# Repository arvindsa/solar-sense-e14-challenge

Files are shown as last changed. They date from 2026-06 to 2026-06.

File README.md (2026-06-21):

# SolarSense: Smart Solar Panel Monitoring System

A comprehensive IoT system for real-time solar panel soiling detection using multi-sensor fusion and edge AI. This project monitors three solar panels -one kept clean as a reference baseline to quantify soiling-induced efficiency losses in real time.

**Important: There is an issue with charging circuit. So do not replicate this project unless you know electronics well.**

## Project Overview

SolarSense uses a clean reference panel to cancel out weather effects completely (both panels see the same sky), leaving only soiling-induced losses measurable. The system combines:

- **Hardware**: Custom STM32L476 sensor board with CAN telemetry
- **Gateway**: Arduino UNO Q with dual STM32U585 (bare-metal HAL) and Linux bridge
- **Dashboard**: LabVIEW-based live visualization
- **AI**: Edge Impulse model for clean/alert/soiled classification

**Current Status**: Phase 1 (data collection and live dashboard) complete. Full pipeline implemented but pending end-to-end hardware validation.

Write-up: https://community.element14.com/challenges-projects/design-challenges/on-the-line/b/projects/posts/solarsense---edge-ai-for-optimal-cleaning-of-solar-panels

## Repository Structure

```
firmware/
├── solar-sense-stm32l476/       # Main sensor board (STM32L476RGT6)
├── arduinoq-stm32u585/          # Gateway STM controller (bare-metal HAL)
│   └── bridge/                  # CAN frame bridging logic
└── arduinoq-linux/              # Gateway Linux side (Python bridge)

labview/                         # Dashboard VIs for Window
hardware/                        # PCB schematics and production files
```

Do not use the Python file inside the labview folder. It's only for testing purpose

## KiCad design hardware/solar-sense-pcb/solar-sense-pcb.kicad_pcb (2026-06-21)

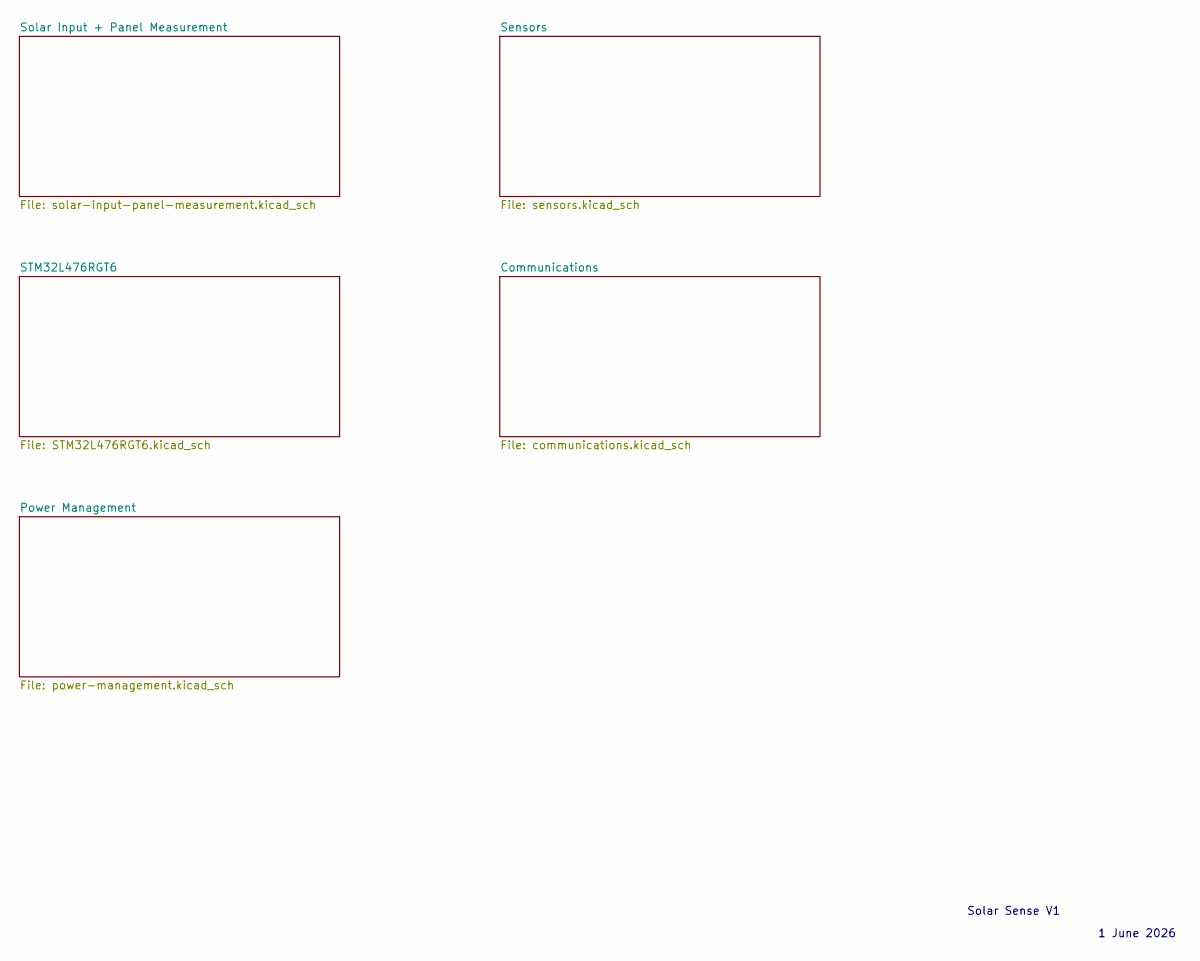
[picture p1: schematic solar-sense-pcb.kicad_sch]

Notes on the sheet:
1 June 2026
Solar Sense V1

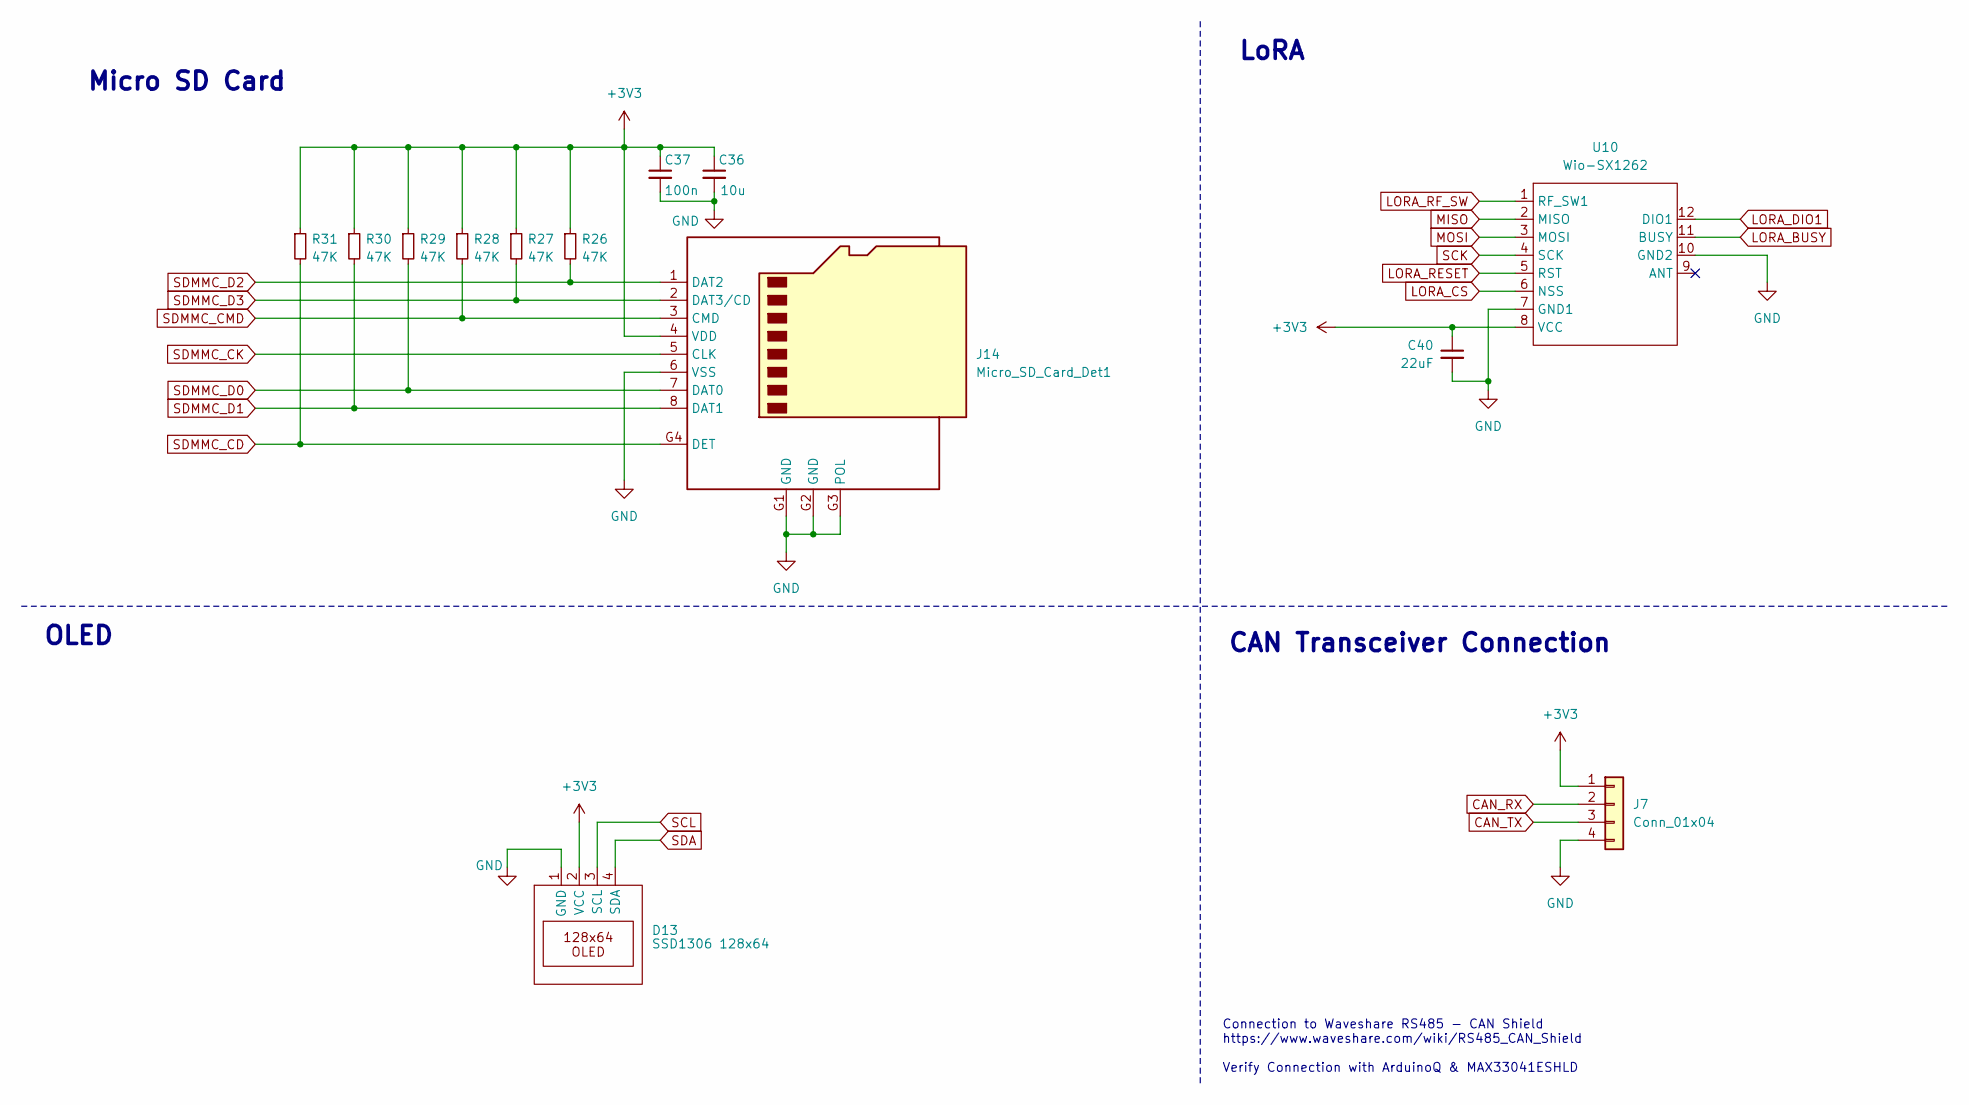
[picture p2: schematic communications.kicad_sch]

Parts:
C36: 10u; C_0603_1608Metric_Pad1.08x0.95mm_HandSolder
C37: 100n; C_0603_1608Metric_Pad1.08x0.95mm_HandSolder
C40: 22uF; C_0603_1608Metric
D13: SSD1306 128x64; JST_XH_B4B-XH-A_1x04_P2.50mm_Vertical
J7: Conn_01x04; JST_XH_B4B-XH-A_1x04_P2.50mm_Vertical
J14: Micro_SD_Card_Det1; microSD Molex 47309-2651
R26, R27, R28, R29, R30, R31: 47K; R_0603_1608Metric
U10: Wio-SX1262; Wio-SX1262 PCB Package

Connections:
+3V3: C36.1, C37.1, C40.1, D13.2 (VCC), J7.1, J14.4 (VDD), R26.1, R27.1, R28.1, R29.1, R30.1, R31.1, U10.8 (VCC); also elsewhere on the board
CAN_RX: J7.2; also elsewhere on the board
CAN_TX: J7.3; also elsewhere on the board
GND: C36.2, C37.2, C40.2, D13.1 (GND), J7.4, J14.6 (VSS), J14.G1 (GND), J14.G2 (GND), J14.G3 (POL), U10.7 (GND1), U10.10 (GND2); also elsewhere on the board
LORA_BUSY: U10.11 (BUSY); also elsewhere on the board
LORA_CS: U10.6 (NSS); also elsewhere on the board
LORA_DIO1: U10.12 (DIO1); also elsewhere on the board
LORA_RESET: U10.5 (RST); also elsewhere on the board
LORA_RF_SW: U10.1 (RF_SW1); also elsewhere on the board
MISO: U10.2 (MISO); also elsewhere on the board
MOSI: U10.3 (MOSI); also elsewhere on the board
SCK: U10.4 (SCK); also elsewhere on the board
SCL: D13.3 (SCL); also elsewhere on the board
SDA: D13.4 (SDA); also elsewhere on the board
SDMMC_CD: J14.G4 (DET), R31.2; also elsewhere on the board
SDMMC_CK: J14.5 (CLK); also elsewhere on the board
SDMMC_CMD: J14.3 (CMD), R28.2; also elsewhere on the board
SDMMC_D0: J14.7 (DAT0), R29.2; also elsewhere on the board
SDMMC_D1: J14.8 (DAT1), R30.2; also elsewhere on the board
SDMMC_D2: J14.1 (DAT2), R26.2; also elsewhere on the board
SDMMC_D3: J14.2 (DAT3/CD), R27.2; also elsewhere on the board

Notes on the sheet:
Micro SD Card
CAN Transceiver Connection
Connection to Waveshare RS485 - CAN Shield https://www.waveshare.com/wiki/RS485_CAN_Shield Verify Connection with ArduinoQ & MAX33041ESHLD
LoRA
OLED

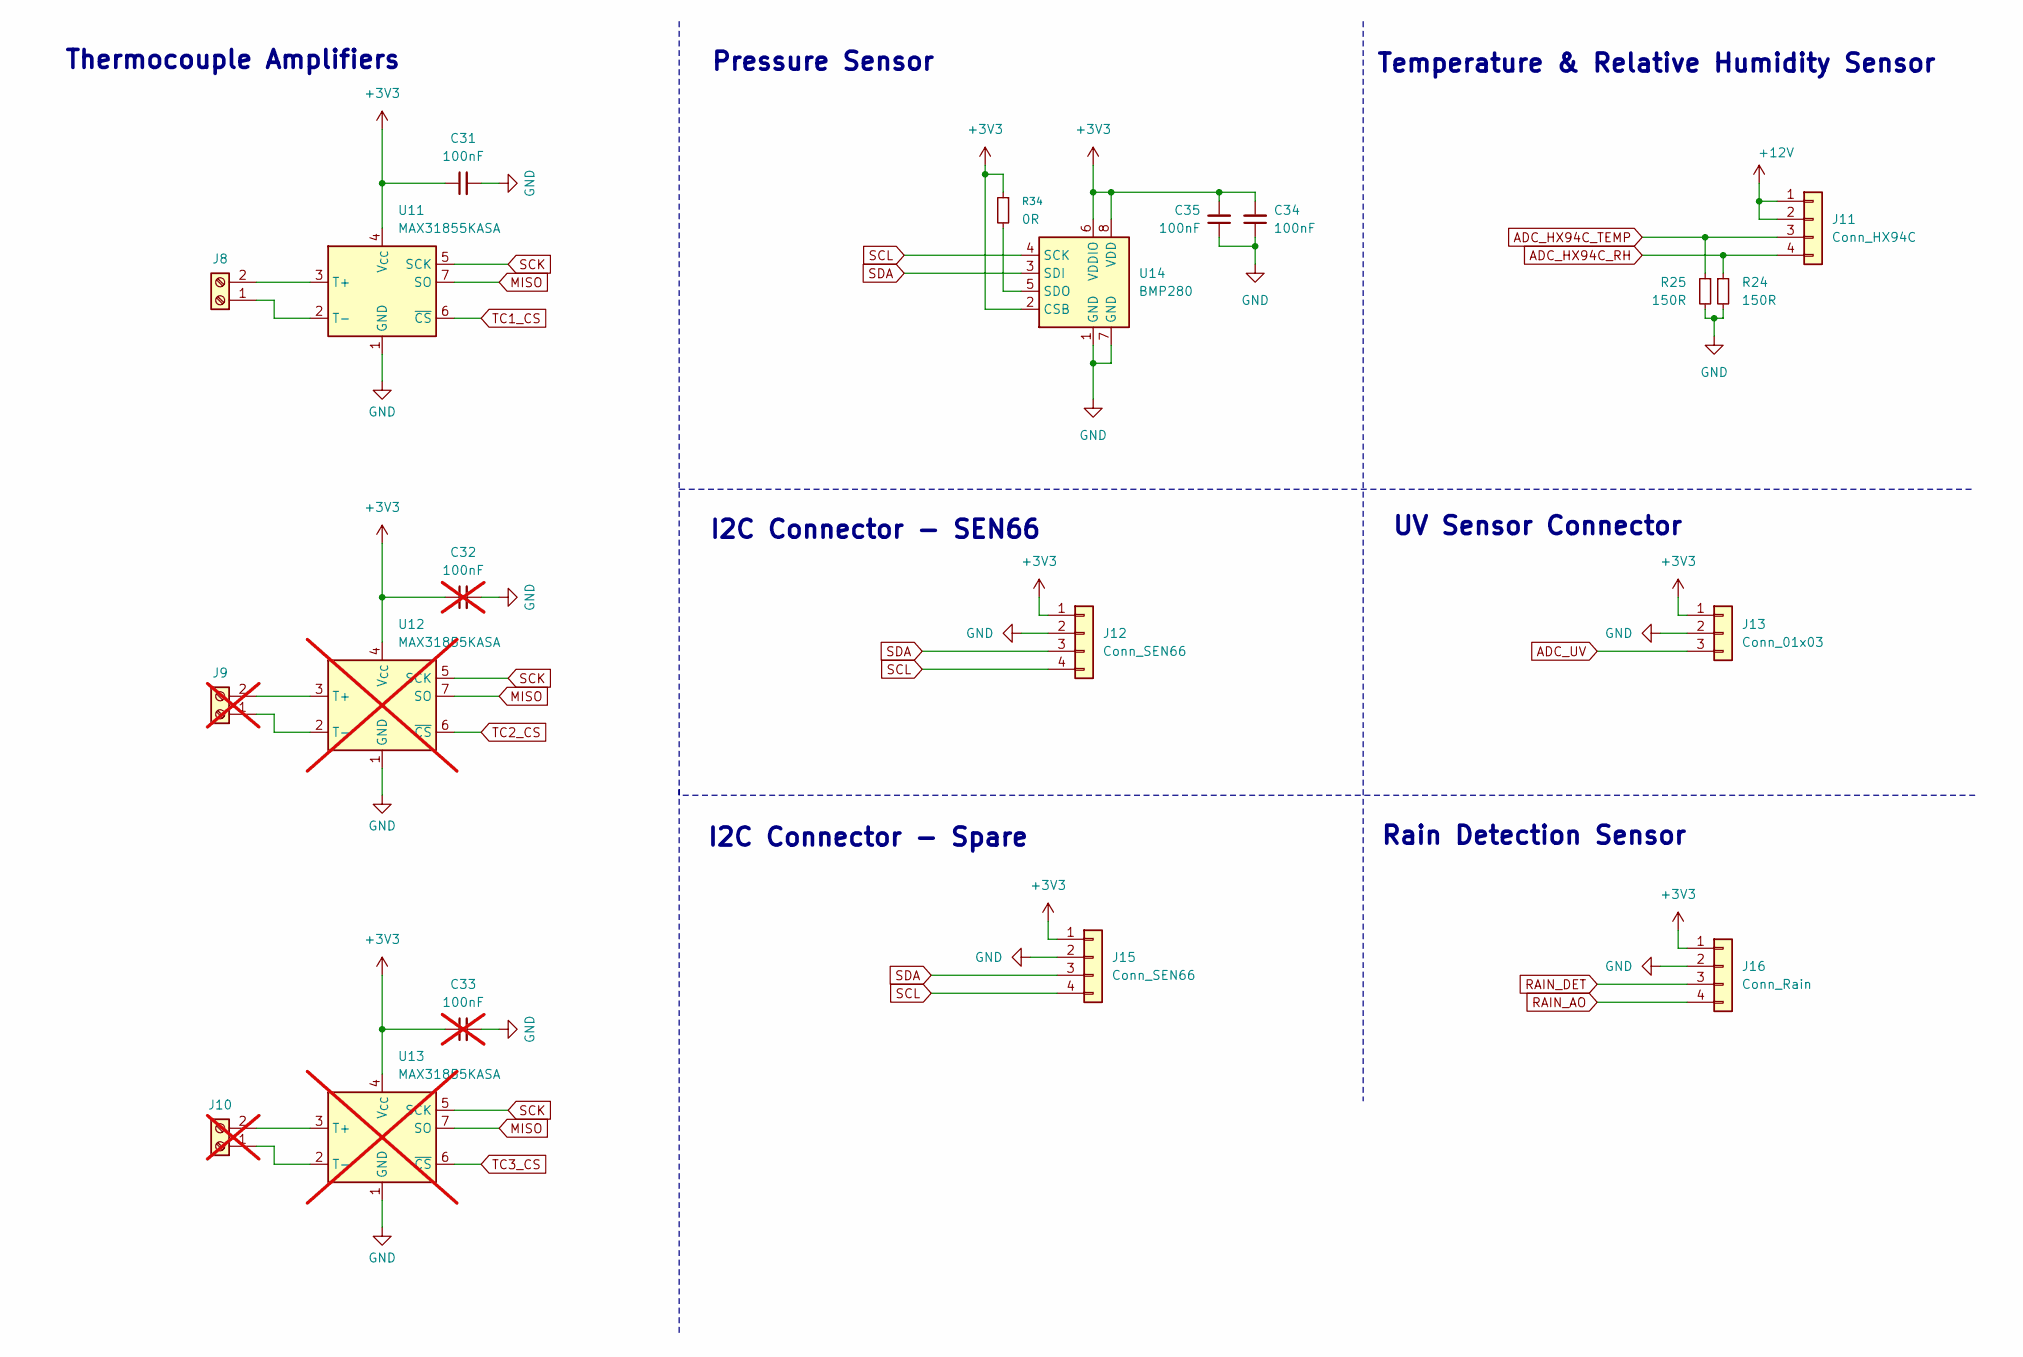
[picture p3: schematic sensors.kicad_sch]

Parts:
C31, C34, C35: 100nF; C_0603_1608Metric
C32, C33: 100nF; C_0603_1608Metric; not fitted
J8: Screw_Terminal_01x02; TerminalBlock_4Ucon_1x02_P3.50mm_Vertical
J9, J10: Screw_Terminal_01x02; TerminalBlock_4Ucon_1x02_P3.50mm_Vertical; not fitted
J11: Conn_HX94C; JST_XH_B4B-XH-A_1x04_P2.50mm_Vertical
J12, J15: Conn_SEN66; JST_XH_B4B-XH-A_1x04_P2.50mm_Vertical
J13: Conn_01x03; JST_XH_B3B-XH-A_1x03_P2.50mm_Vertical
J16: Conn_Rain; JST_XH_B4B-XH-A_1x04_P2.50mm_Vertical
R24, R25: 150R; LED_0805_2012Metric
R34: 0R; R_0603_1608Metric
U11: MAX31855KASA; SOIC-8_3.9x4.9mm_P1.27mm
U12, U13: MAX31855KASA; SOIC-8_3.9x4.9mm_P1.27mm; not fitted
U14: BMP280; Bosch_LGA-8_2x2.5mm_P0.65mm_ClockwisePinNumbering

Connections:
+3V3: C31.1, C32.1, C33.1, C34.2, C35.2, J12.1, J13.1, J15.1, J16.1, R34.1, U11.4 (V_{CC}), U12.4 (V_{CC}), U13.4 (V_{CC}), U14.2 (CSB), U14.6 (VDDIO), U14.8 (VDD); also elsewhere on the board
+12V: J11.1, J11.2; also elsewhere on the board
ADC_HX94C_RH: J11.4, R24.1; also elsewhere on the board
ADC_HX94C_TEMP: J11.3, R25.1; also elsewhere on the board
ADC_UV: J13.3; also elsewhere on the board
GND: C31.2, C32.2, C33.2, C34.1, C35.1, J12.2, J13.2, J15.2, J16.2, R24.2, R25.2, U11.1 (GND), U12.1 (GND), U13.1 (GND), U14.1 (GND), U14.7 (GND); also elsewhere on the board
MISO: U11.7 (SO), U12.7 (SO), U13.7 (SO); also elsewhere on the board
unnamed: J8.1, U11.2 (T-)
unnamed: J8.2, U11.3 (T+)
unnamed: J9.1, U12.2 (T-)
unnamed: J9.2, U12.3 (T+)
unnamed: J10.1, U13.2 (T-)
unnamed: J10.2, U13.3 (T+)
unnamed: R34.2, U14.5 (SDO)
RAIN_AO: J16.4; also elsewhere on the board
RAIN_DET: J16.3; also elsewhere on the board
SCK: U11.5 (SCK), U12.5 (SCK), U13.5 (SCK); also elsewhere on the board
SCL: J12.4, J15.4, U14.4 (SCK); also elsewhere on the board
SDA: J12.3, J15.3, U14.3 (SDI); also elsewhere on the board
TC1_CS: U11.6 (~CS); also elsewhere on the board
TC2_CS: U12.6 (~CS); also elsewhere on the board
TC3_CS: U13.6 (~CS); also elsewhere on the board

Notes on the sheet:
I2C Connector - SEN66
I2C Connector - Spare
Pressure Sensor
UV Sensor Connector
Temperature & Relative Humidity Sensor
Thermocouple Amplifiers
Rain Detection Sensor

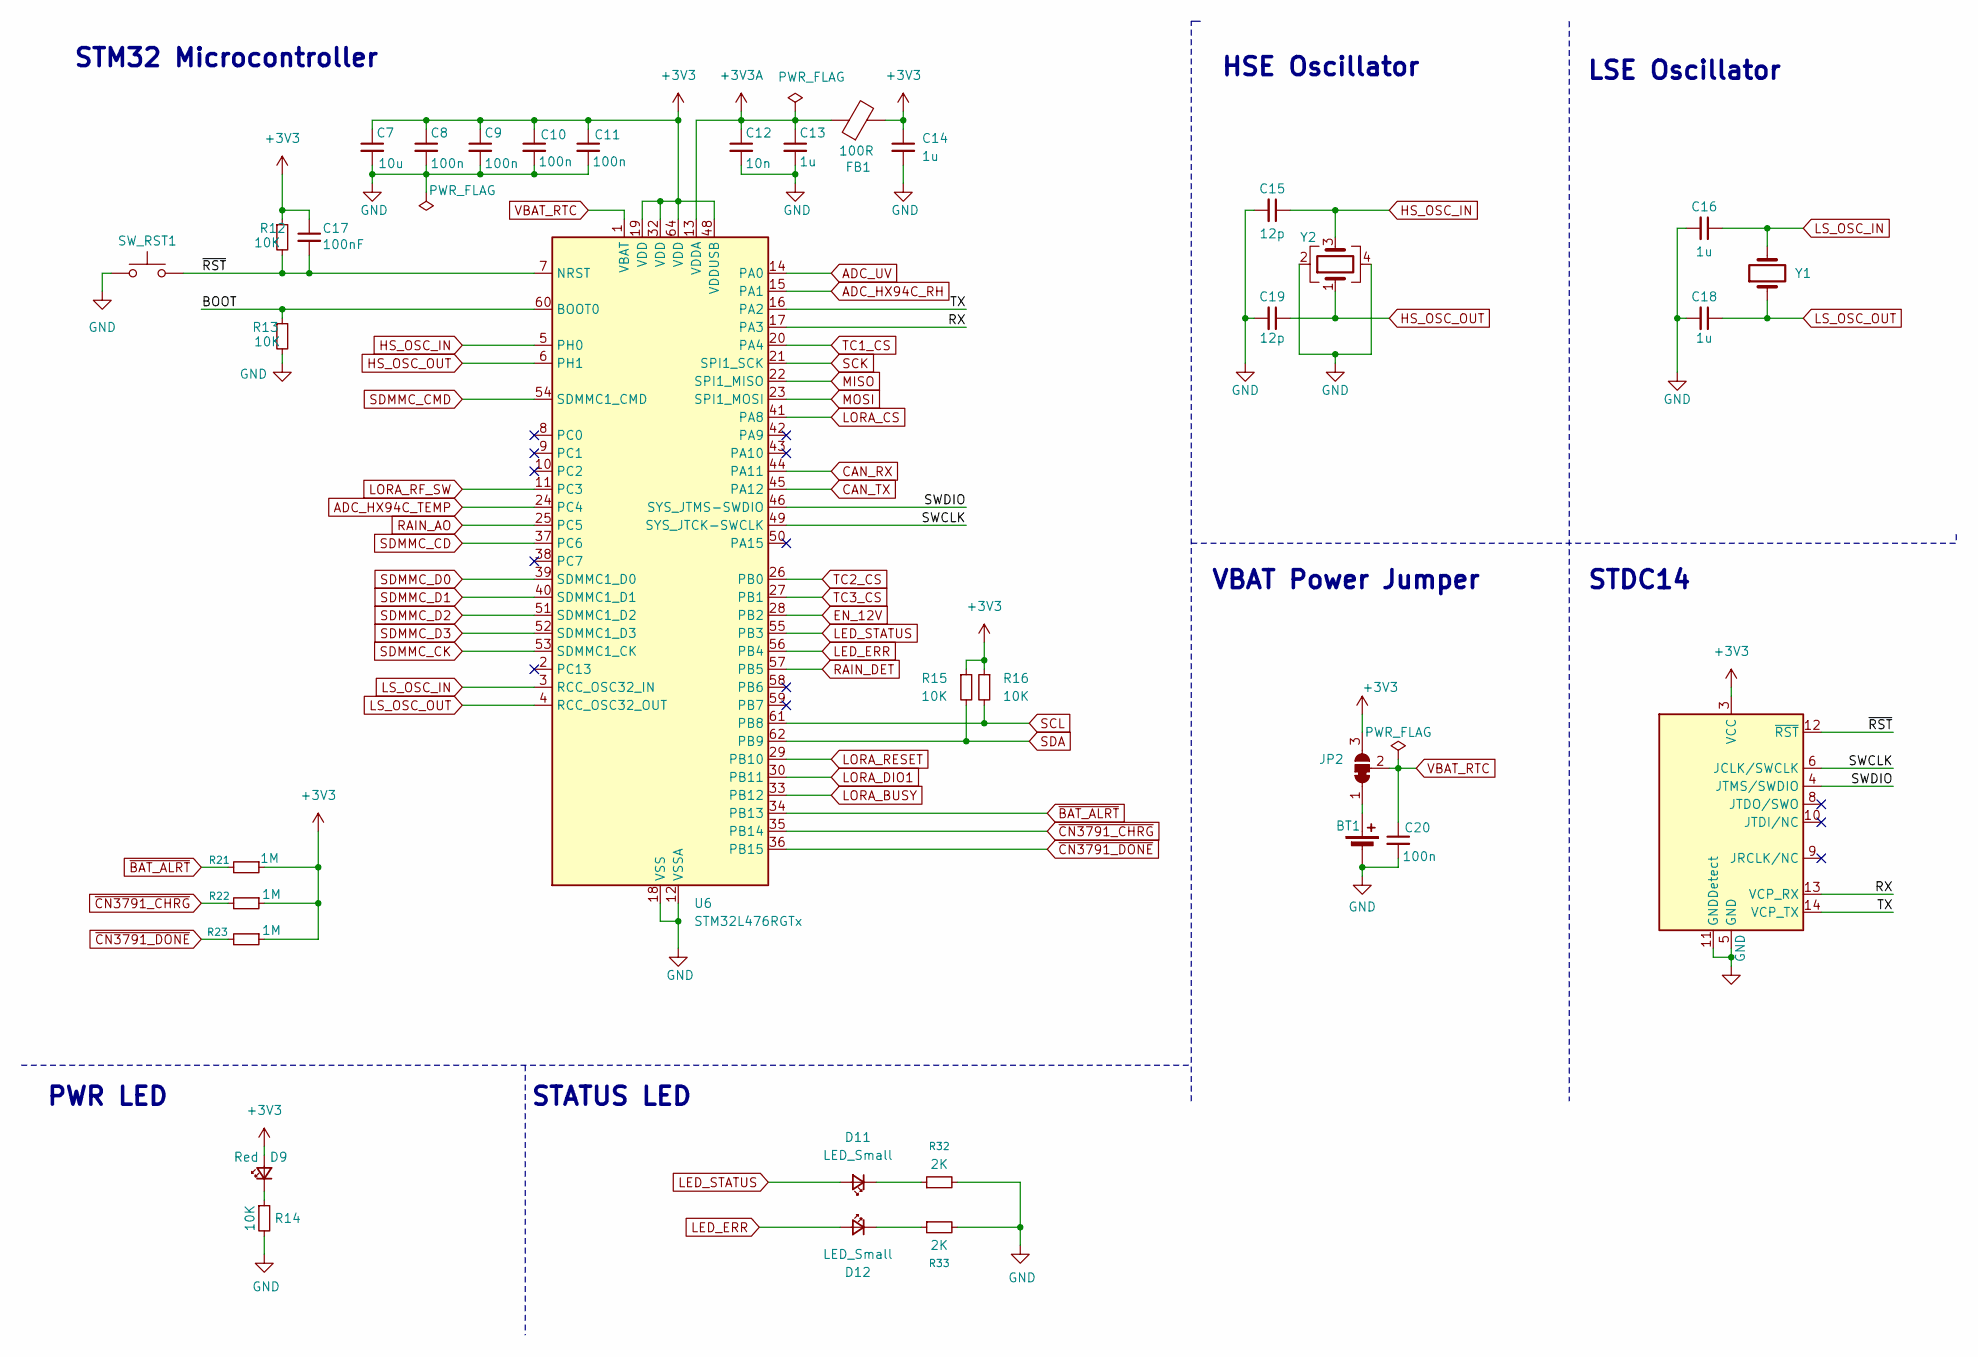
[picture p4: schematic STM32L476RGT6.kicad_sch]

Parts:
BT1: Battery_Cell; CH7410-2032LF
C7: 10u; C_0603_1608Metric_Pad1.08x0.95mm_HandSolder
C8, C9, C10, C11, C20: 100n; C_0603_1608Metric_Pad1.08x0.95mm_HandSolder
C12: 10n; C_0603_1608Metric_Pad1.08x0.95mm_HandSolder
C13, C14, C16, C18: 1u; C_0603_1608Metric_Pad1.08x0.95mm_HandSolder
C15, C19: 12p; C_0603_1608Metric_Pad1.08x0.95mm_HandSolder
C17: 100nF; C_0603_1608Metric
D9: Red; LED_0603_1608Metric_Pad1.05x0.95mm_HandSolder
D11, D12: LED_Small; LED_0603_1608Metric
FB1: 100R; R_0603_1608Metric_Pad0.98x0.95mm_HandSolder
J6: Conn_ST_STDC14; PinHeader_2x07_P1.27mm_Vertical_SMD
JP2: SolderJumper_3_Bridged12; SolderJumper-3_P1.3mm_Bridged12_RoundedPad1.0x1.5mm
R12, R13, R15, R16: 10K; R_0603_1608Metric
R14: 10K; R_0603_1608Metric_Pad0.98x0.95mm_HandSolder
R21, R22, R23: 1M; R_0603_1608Metric
R32, R33: 2K; R_0603_1608Metric
SW_RST1: SW_Push; SW_Tactile_SPST_NO_Straight_CK_PTS636Sx25SMTRLFS
U6: STM32L476RGTx; LQFP-64_10x10mm_P0.5mm
Y1: CM7V-T1A-32.768kHz-9pF-20PPM-TA-QC; Crystal_SMD_3215-2Pin_3.2x1.5mm
Y2: 7M-16.000MAAJ-T; Crystal_SMD_TXC_7M-4Pin_3.2x2.5mm

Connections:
+3V3: C7.1, C8.1, C9.1, C10.1, C11.1, C14.1, C17.1, D9.2 (A), FB1.2, J6.3 (VCC), JP2.3 (B), R12.1, R15.1, R16.1, R21.1, R22.1, R23.1, U6.19 (VDD), U6.32 (VDD), U6.48 (VDDUSB), U6.64 (VDD); also elsewhere on the board
+3V3A: C12.1, C13.1, FB1.1, U6.13 (VDDA)
/STM32L476RGT6/BOOT: R13.1, U6.60 (BOOT0)
/STM32L476RGT6/RX: J6.13 (VCP_RX), U6.17 (PA3)
/STM32L476RGT6/SWCLK: J6.6 (JCLK/SWCLK), U6.49 (SYS_JTCK-SWCLK)
/STM32L476RGT6/SWDIO: J6.4 (JTMS/SWDIO), U6.46 (SYS_JTMS-SWDIO)
/STM32L476RGT6/TX: J6.14 (VCP_TX), U6.16 (PA2)
/STM32L476RGT6/~RST: C17.2, J6.12 (~RST), R12.2, SW_RST1.2, U6.7 (NRST)
ADC_HX94C_RH: U6.15 (PA1); also elsewhere on the board
ADC_HX94C_TEMP: U6.24 (PC4); also elsewhere on the board
ADC_UV: U6.14 (PA0); also elsewhere on the board
CAN_RX: U6.44 (PA11); also elsewhere on the board
CAN_TX: U6.45 (PA12); also elsewhere on the board
EN_12V: U6.28 (PB2); also elsewhere on the board
GND: BT1.2 (-), C7.2, C8.2, C9.2, C10.2, C11.2, C12.2, C13.2, C14.2, C15.2, C16.2, C18.2, C19.2, C20.2, J6.5 (GND), J6.7 (GND), J6.11 (GNDDetect), R13.2, R14.2, R32.2, R33.2, SW_RST1.1, U6.12 (VSSA), U6.18 (VSS), U6.31 (VSS), U6.47 (VSS), U6.63 (VSS), Y2.2, Y2.4; also elsewhere on the board
HS_OSC_IN: C15.1, U6.5 (PH0), Y2.3
HS_OSC_OUT: C19.1, U6.6 (PH1), Y2.1
LED_ERR: D12.2 (A), U6.56 (PB4)
LED_STATUS: D11.2 (A), U6.55 (PB3)
LORA_BUSY: U6.33 (PB12); also elsewhere on the board
LORA_CS: U6.41 (PA8); also elsewhere on the board
LORA_DIO1: U6.30 (PB11); also elsewhere on the board
LORA_RESET: U6.29 (PB10); also elsewhere on the board
LORA_RF_SW: U6.11 (PC3); also elsewhere on the board
LS_OSC_IN: C16.1, U6.3 (RCC_OSC32_IN), Y1.2
LS_OSC_OUT: C18.1, U6.4 (RCC_OSC32_OUT), Y1.1
MISO: U6.22 (SPI1_MISO); also elsewhere on the board
MOSI: U6.23 (SPI1_MOSI); also elsewhere on the board
unnamed: BT1.1 (+), JP2.1 (A)
unnamed: D9.1 (K), R14.1
unnamed: D11.1 (K), R32.1
unnamed: D12.1 (K), R33.1
RAIN_AO: U6.25 (PC5); also elsewhere on the board
RAIN_DET: U6.57 (PB5); also elsewhere on the board
SCK: U6.21 (SPI1_SCK); also elsewhere on the board
SCL: R16.2, U6.61 (PB8); also elsewhere on the board
SDA: R15.2, U6.62 (PB9); also elsewhere on the board
SDMMC_CD: U6.37 (PC6); also elsewhere on the board
SDMMC_CK: U6.53 (SDMMC1_CK); also elsewhere on the board
SDMMC_CMD: U6.54 (SDMMC1_CMD); also elsewhere on the board
SDMMC_D0: U6.39 (SDMMC1_D0); also elsewhere on the board
SDMMC_D1: U6.40 (SDMMC1_D1); also elsewhere on the board
SDMMC_D2: U6.51 (SDMMC1_D2); also elsewhere on the board
SDMMC_D3: U6.52 (SDMMC1_D3); also elsewhere on the board
TC1_CS: U6.20 (PA4); also elsewhere on the board
TC2_CS: U6.26 (PB0); also elsewhere on the board
TC3_CS: U6.27 (PB1); also elsewhere on the board
VBAT_RTC: C20.1, JP2.2 (C), U6.1 (VBAT)
~BAT_ALRT: R21.2, U6.34 (PB13); also elsewhere on the board
~CN3791_CHRG: R22.2, U6.35 (PB14); also elsewhere on the board
~CN3791_DONE: R23.2, U6.36 (PB15); also elsewhere on the board

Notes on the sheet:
LSE Oscillator
VBAT Power Jumper
STM32 Microcontroller
PWR LED
STATUS LED
HSE Oscillator
STDC14

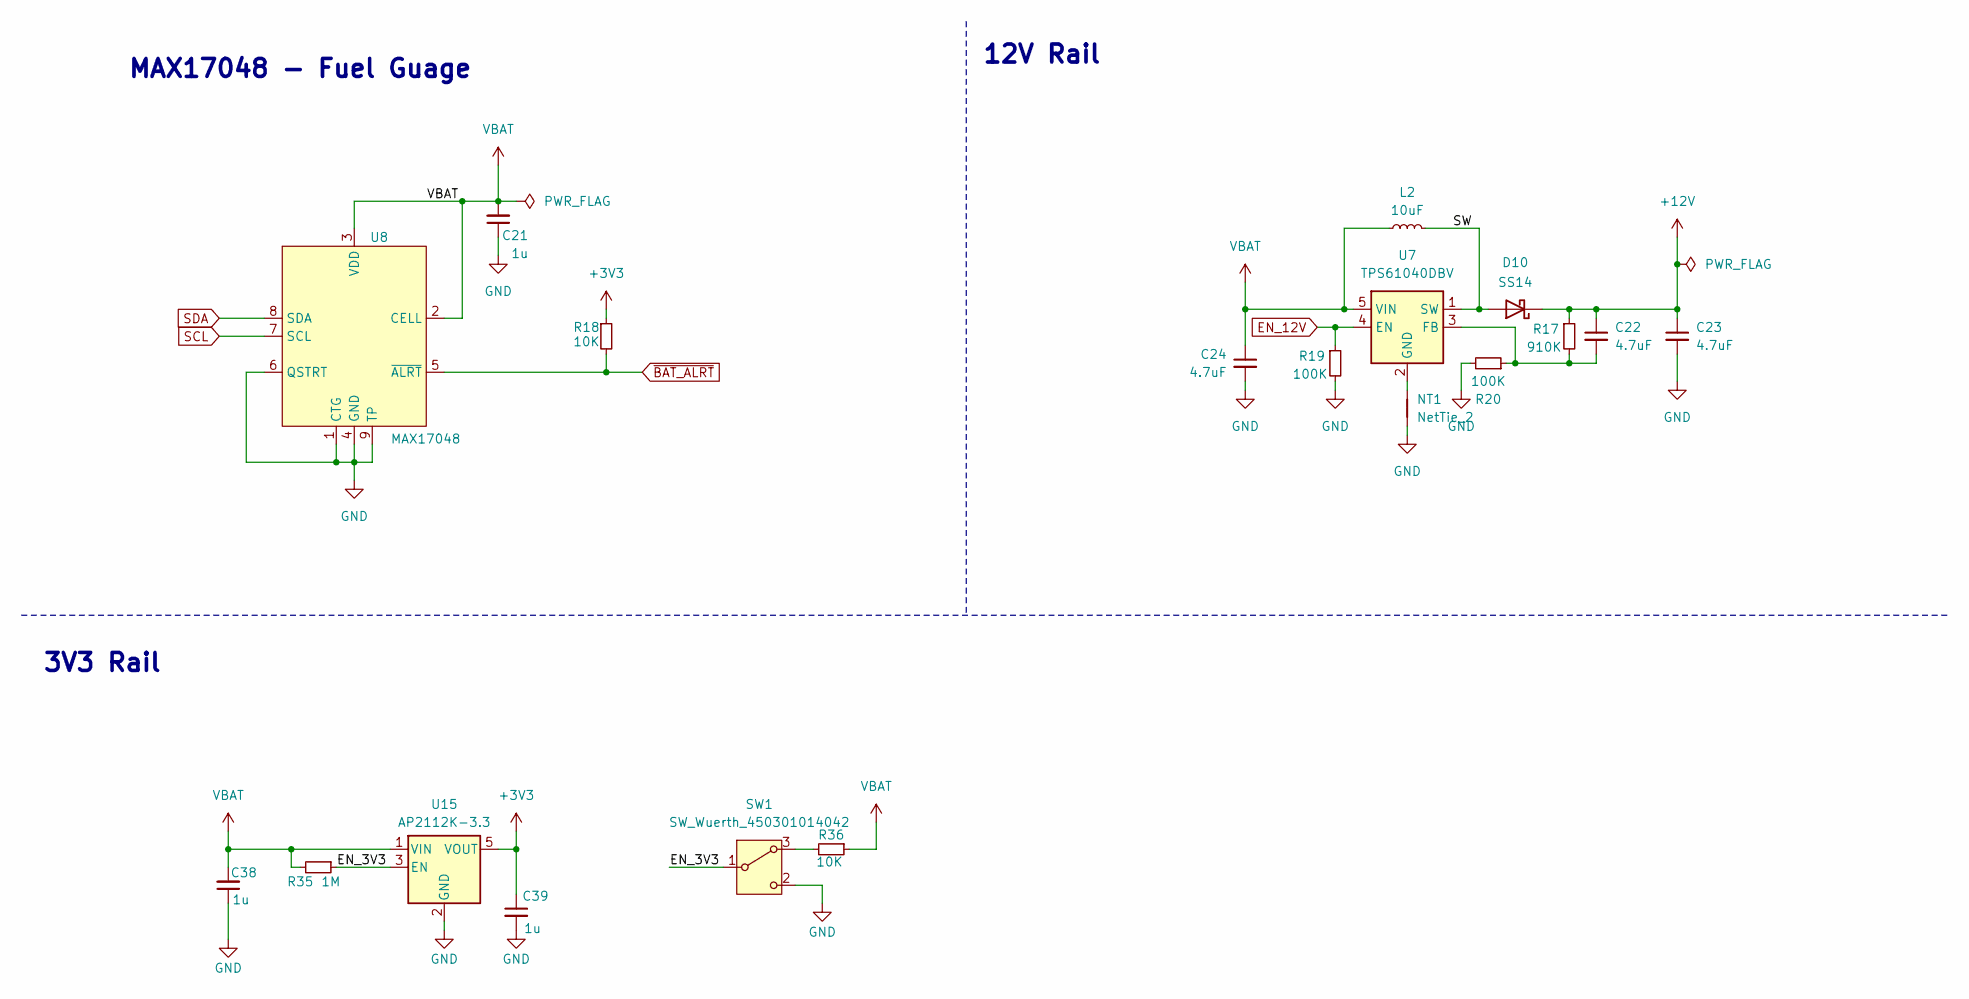
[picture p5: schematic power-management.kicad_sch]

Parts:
C21: 1u; C_0603_1608Metric_Pad1.08x0.95mm_HandSolder
C22, C23, C24: 4.7uF; C_0603_1608Metric
C38, C39: 1u; C_0603_1608Metric
D10: SS14; D_SMA
L2: 10uF; L_TDK_VLS6045EX_VLS6045AF
NT1: NetTie_2; NetTie-2_SMD_Pad0.5mm
R17: 910K; R_0603_1608Metric
R18: 10K; R_0603_1608Metric_Pad0.98x0.95mm_HandSolder
R19, R20: 100K; R_0603_1608Metric
R35: 1M; R_0603_1608Metric
R36: 10K; R_0603_1608Metric
SW1: SW_Wuerth_450301014042; Weurth 450302014072 - Overhang
U7: TPS61040DBV; SOT-23-5
U8: MAX17048; MAX17048G+T10
U15: AP2112K-3.3; SOT-23-5

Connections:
+3V3: C39.1, R18.1, U15.5 (VOUT); also elsewhere on the board
+12V: C22.1, C23.1, D10.1 (K), R17.1; also elsewhere on the board
/Power Management/EN_3V3: R35.1, SW1.1 (B), U15.3 (EN)
/Power Management/SW: D10.2 (A), L2.2, U7.1 (SW)
EN_12V: R19.1, U7.4 (EN); also elsewhere on the board
GND: C21.1, C23.2, C24.2, C38.1, C39.2, NT1.1, R19.2, R20.2, SW1.2 (C), U8.1 (CTG), U8.4 (GND), U8.6 (QSTRT), U8.9 (TP), U15.2 (GND); also elsewhere on the board
unnamed: R36.2, SW1.3 (A)
unnamed: C22.2, R17.2, R20.1, U7.3 (FB)
unnamed: NT1.2, U7.2 (GND)
SCL: U8.7 (SCL); also elsewhere on the board
SDA: U8.8 (SDA); also elsewhere on the board
VBAT: C21.2, C24.1, C38.2, L2.1, R35.2, R36.1, U7.5 (VIN), U8.2 (CELL), U8.3 (VDD), U15.1 (VIN); also elsewhere on the board
~BAT_ALRT: R18.2, U8.5 (~ALRT); also elsewhere on the board

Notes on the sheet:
12V Rail
MAX17048 - Fuel Guage
3V3 Rail

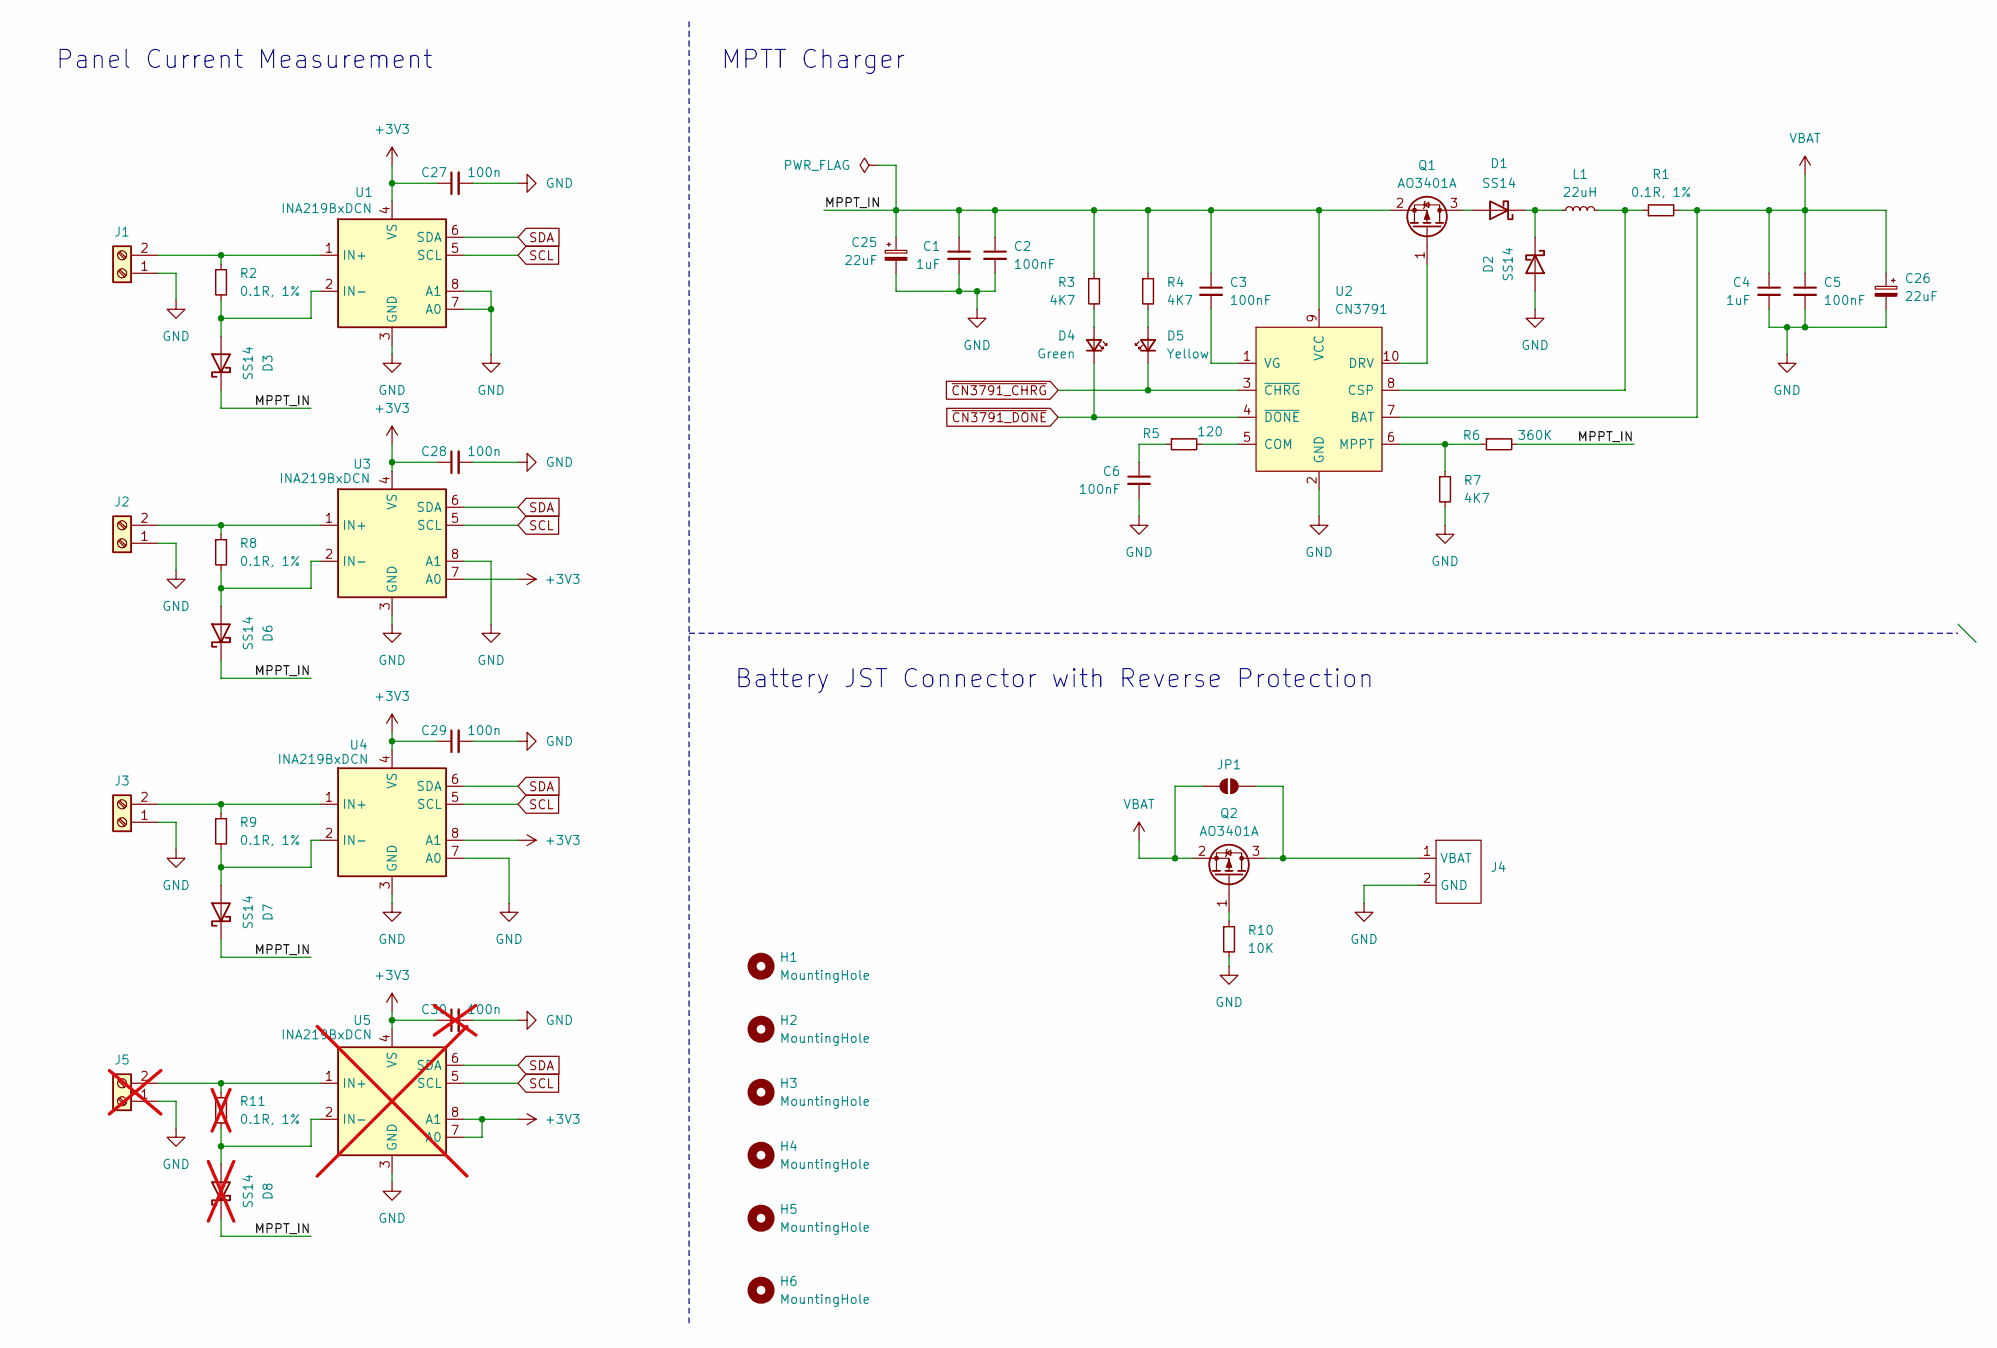
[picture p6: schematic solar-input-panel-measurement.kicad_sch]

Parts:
C1, C4: 1uF; C_0603_1608Metric
C2, C3, C5, C6: 100nF; C_0603_1608Metric
C25, C26: 22uF; CP_Elec_5x5.3
C27, C28, C29: 100n; C_0603_1608Metric_Pad1.08x0.95mm_HandSolder
C30: 100n; C_0603_1608Metric_Pad1.08x0.95mm_HandSolder; not fitted
D1, D2, D3, D6, D7: SS14; D_SMA
D4: Green; LED_0603_1608Metric
D5: Yellow; LED_0603_1608Metric
D8: SS14; D_SMA; not fitted
H1, H2, H3, H4, H5, H6: MountingHole; MountingHole_3.2mm_M3
J1, J2, J3: Screw_Terminal_01x02; TerminalBlock_4Ucon_1x02_P3.50mm_Vertical
J4: JST_PH_S2B-PH-SM4-TB_1x02-1MP_P2.00mm_Horizontal
J5: Screw_Terminal_01x02; TerminalBlock_4Ucon_1x02_P3.50mm_Vertical; not fitted
JP1: SolderJumper_2_Open; SolderJumper-2_P1.3mm_Open_RoundedPad1.0x1.5mm
L1: 22uH; L_Sunlord_SWPA8040S
Q1, Q2: AO3401A; SOT-23
R1: 0.1R, 1%; R_1210_3225Metric
R2, R8, R9: 0.1R, 1%; R_2512_6332Metric
R3, R4, R7: 4K7; R_0603_1608Metric
R5: 120; R_0603_1608Metric
R6: 360K; R_0603_1608Metric
R10: 10K; R_0603_1608Metric
R11: 0.1R, 1%; R_2512_6332Metric; not fitted
U1, U3, U4: INA219BxDCN; SOT-23-8
U2: CN3791; SSOP-10-1EP_3.9x4.9mm_P1mm_EP2.1x3.3mm_ThermalVias
U5: INA219BxDCN; SOT-23-8; not fitted

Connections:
+3V3: C27.1, C28.1, C29.1, C30.1, U1.4 (VS), U3.4 (VS), U3.7 (A0), U4.4 (VS), U4.8 (A1), U5.4 (VS), U5.7 (A0), U5.8 (A1); also elsewhere on the board
/Solar Input + Panel Measurement/MPPT_IN: C1.1, C2.1, C3.1, C25.1, D3.1 (K), D6.1 (K), D7.1 (K), D8.1 (K), Q1.2 (S), R3.1, R4.1, R6.2, U2.9 (VCC)
GND: C1.2, C2.2, C4.2, C5.2, C6.2, C25.2, C26.2, C27.2, C28.2, C29.2, C30.2, D2.2 (A), J1.1, J2.1, J3.1, J4.2 (GND), J5.1, R7.2, R10.2, U1.3 (GND), U1.7 (A0), U1.8 (A1), U2.2 (GND), U3.3 (GND), U3.8 (A1), U4.3 (GND), U4.7 (A0), U5.3 (GND); also elsewhere on the board
unnamed: C6.1, R5.1
unnamed: D1.2 (A), Q1.3 (D)
unnamed: D1.1 (K), D2.1 (K), L1.1
unnamed: D3.2 (A), R2.2, U1.2 (IN-)
unnamed: D4.2 (A), R3.2
unnamed: D5.2 (A), R4.2
unnamed: D6.2 (A), R8.2, U3.2 (IN-)
unnamed: D7.2 (A), R9.2, U4.2 (IN-)
unnamed: D8.2 (A), R11.2, U5.2 (IN-)
unnamed: J1.2, R2.1, U1.1 (IN+)
unnamed: J2.2, R8.1, U3.1 (IN+)
unnamed: J3.2, R9.1, U4.1 (IN+)
unnamed: J4.1 (VBAT), JP1.2 (B), Q2.3 (D)
unnamed: J5.2, R11.1, U5.1 (IN+)
unnamed: Q1.1 (G), U2.10 (DRV)
unnamed: Q2.1 (G), R10.1
unnamed: R5.2, U2.5 (COM)
unnamed: L1.2, R1.1, U2.8 (CSP)
unnamed: R6.1, R7.1, U2.6 (MPPT)
unnamed: C3.2, U2.1 (VG)
SCL: U1.5 (SCL), U3.5 (SCL), U4.5 (SCL), U5.5 (SCL); also elsewhere on the board
SDA: U1.6 (SDA), U3.6 (SDA), U4.6 (SDA), U5.6 (SDA); also elsewhere on the board
VBAT: C4.1, C5.1, C26.1, JP1.1 (A), Q2.2 (S), R1.2, U2.7 (BAT); also elsewhere on the board
~CN3791_CHRG: D5.1 (K), U2.3 (~CHRG); also elsewhere on the board
~CN3791_DONE: D4.1 (K), U2.4 (~DONE); also elsewhere on the board

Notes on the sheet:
MPTT Charger
Battery JST Connector with Reverse Protection
Panel Current Measurement

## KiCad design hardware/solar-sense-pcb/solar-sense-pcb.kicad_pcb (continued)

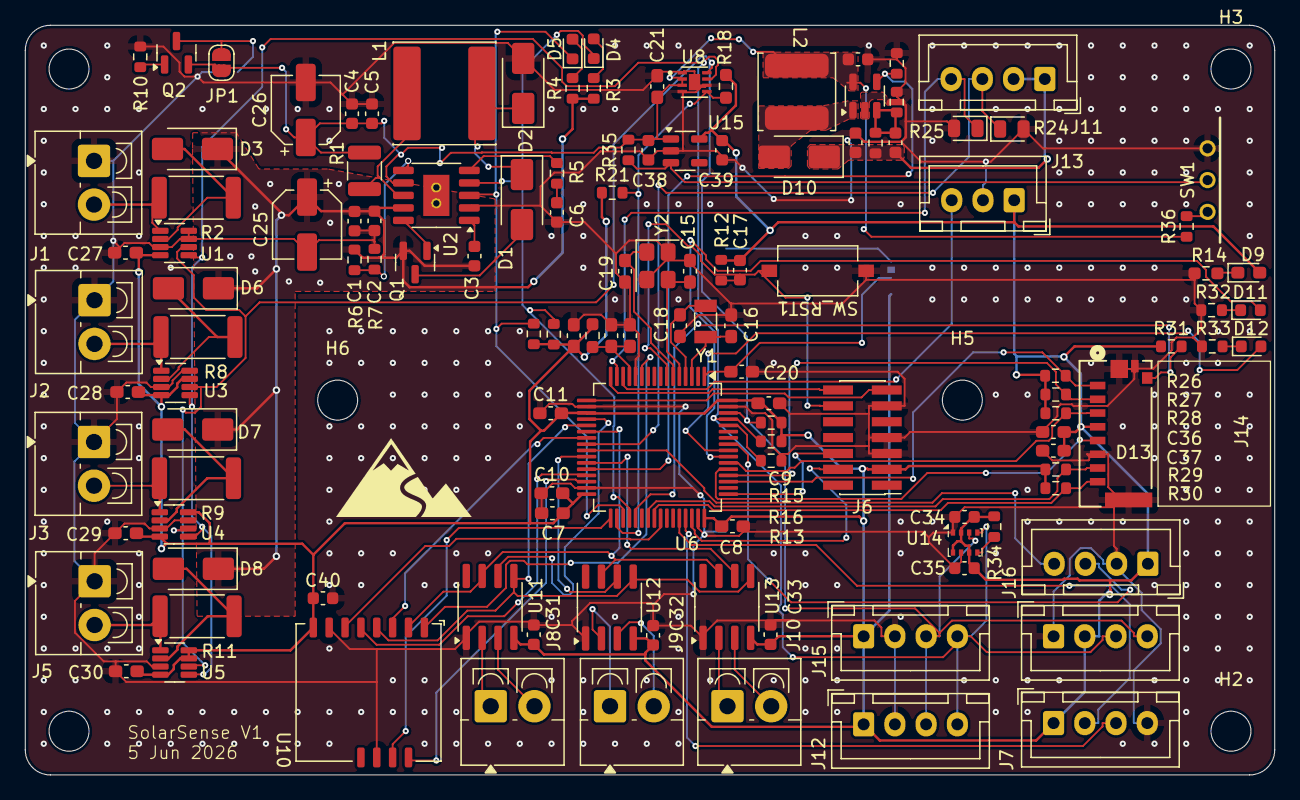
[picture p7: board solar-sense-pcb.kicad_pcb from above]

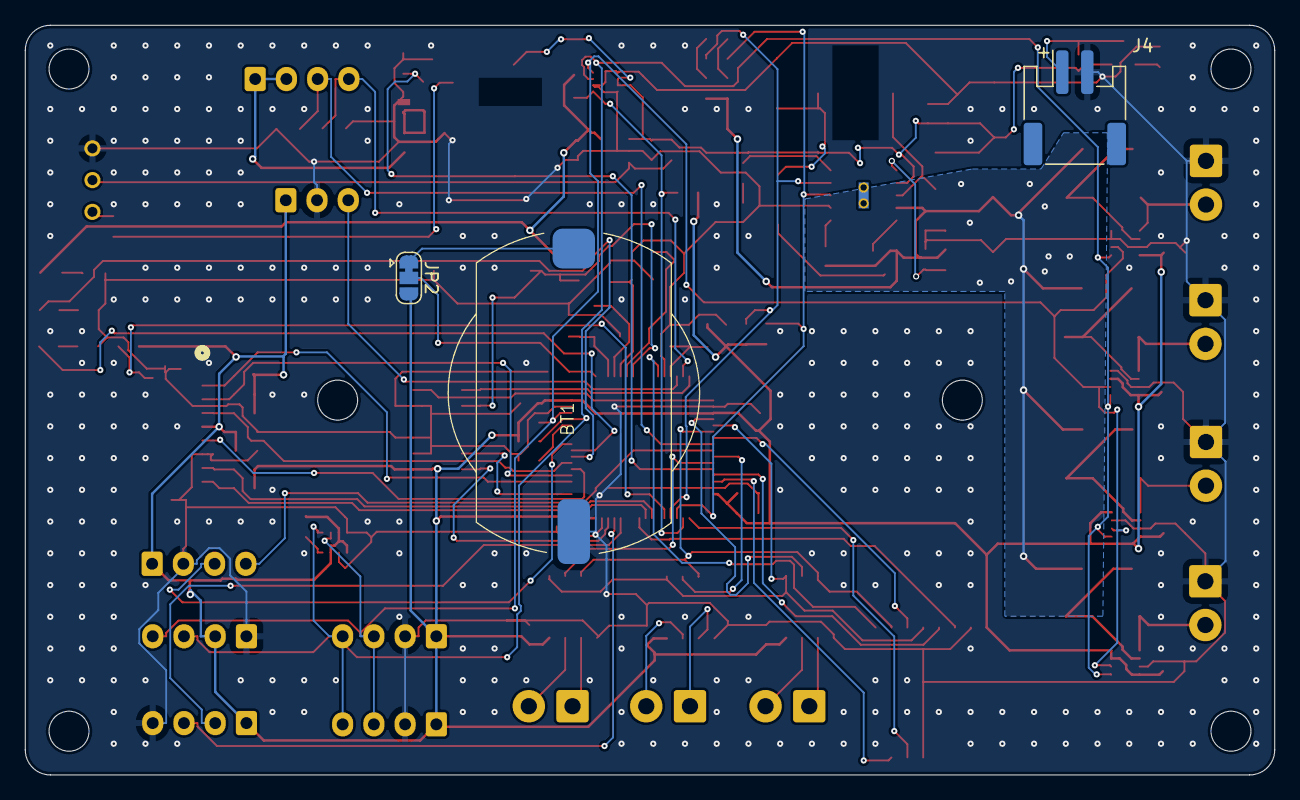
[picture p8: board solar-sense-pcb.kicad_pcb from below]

Board: 2 copper layers, 100.0 x 60.0 mm, 138 parts (3 on the bottom side), 86 nets.

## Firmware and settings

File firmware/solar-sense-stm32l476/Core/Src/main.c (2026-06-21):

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
/* Includes ------------------------------------------------------------------*/
#include "main.h"

/* USER CODE BEGIN Includes */
#include <stdio.h>
#include <stdlib.h>
#include <string.h>
#include "max17048.h"
#include "ina219.h"
#include "max31855.h"
#include "bmp280.h"
#include "hx94c.h"
#include "ssd1306.h"
#include "sen66.h"
#include "can_tlm.h"
/* USER CODE END Includes */

ADC_HandleTypeDef hadc1;

CAN_HandleTypeDef hcan1;

I2C_HandleTypeDef hi2c1;

RTC_HandleTypeDef hrtc;

SD_HandleTypeDef hsd1;

SPI_HandleTypeDef hspi1;

UART_HandleTypeDef huart2;

/* USER CODE BEGIN PV */
static volatile uint8_t bat_alert_flag = 0;  /* set by BAT_ALRT (PB13) EXTI  */
static uint8_t bat_alert_masked = 0;         /* 1 = EXTI off until condition clears */
/* Alert-condition bits that, while present, would re-assert ALRT forever. */
#define BAT_ALERT_CONDITIONS (MAX17048_STATUS_VH | MAX17048_STATUS_VL | \
                              MAX17048_STATUS_VR | MAX17048_STATUS_HD)

/* Per-panel current/voltage monitors. Only the three populated parts are
   instantiated; Panel 4/5 footprints are DNP. */
#define INA219_PANEL_COUNT 3
static INA219_t panel_ina[INA219_PANEL_COUNT];
static const uint8_t panel_ina_addr[INA219_PANEL_COUNT] = {
  INA219_ADDR_PANEL1, INA219_ADDR_PANEL2, INA219_ADDR_PANEL3
};

static MAX31855_t tc3;

/* BMP280 barometric pressure + board temperature (U14, I2C1 @0x76). */
static BMP280_t bmp;

/* HX94C humidity/temperature probe: two 4-20 mA loops on ADC1 (RH=IN6/PA1,
   temp=IN13/PC4), excited from the +12 V rail. Reads are only meaningful while
   r12v is on; with the rail off both loops read as open (HX94C_FLT_*_OPEN). */
static HX94C_t hx;

/* 128x64 SSD1306 status OLED on the shared I2C1 bus (@0x3C). Optional: if it
   isn't fitted, oled.present stays 0 and all display calls become no-ops. */
static SSD1306_t oled;

/* SEN66 multi-sensor: PM1.0/PM2.5/PM4.0/PM10, RH, T, VOC, NOx, CO2 (I2C1 @0x6B). */
static SEN66_t sen;

/* --- host serial command interface (USART2) --------------------------- */

static volatile uint8_t stream_enabled = 1;  /* 1 = emit periodic TLM lines     */
static volatile uint8_t maint_mode = 0;      /* 1 = maintenance mode, stream off */
static volatile uint8_t force_report   = 0;  /* one-shot TLM (from "status" cmd) */
static uint8_t          rx_byte;             /* single-byte IT receive slot      */
static char             rx_buf[40];          /* incoming command-line accumulator*/
static volatile uint8_t rx_len   = 0;
static char             rx_cmd[40];          /* completed command line for main  */
static volatile uint8_t rx_ready = 0;        /* 1 = rx_cmd holds a full line     */
/* USER CODE END PV */

void SystemClock_Config(void);
void PeriphCommonClock_Config(void);
static void MX_GPIO_Init(void);
static void MX_CAN1_Init(void);
static void MX_I2C1_Init(void);
static void MX_SDMMC1_SD_Init(void);
static void MX_SPI1_Init(void);
static void MX_USART2_UART_Init(void);
static void MX_ADC1_Init(void);
static void MX_RTC_Init(void);
/* USER CODE BEGIN PFP */
static void RTC_EmitTime(void);
static uint8_t RTC_SetFromString(const char *s);
static uint8_t RTC_ReadVbat_mV(uint32_t *vbat_mv);
static void OLED_ScreenAQ(void);
static void OLED_RenderScreen(uint8_t screen);
static void Power_EnterStop2(uint32_t seconds);
static void Power_EnterStandby(uint32_t wakeup_s);
/* USER CODE END PFP */

/* USER CODE BEGIN 0 */

/* microSD card detect on PC6 (SDMMC1_CD): active-low with a 10k pull-up to
   +3V3, so the pin reads LOW when a card is seated. */
static uint8_t SD_CardPresent(void)
{
  return (HAL_GPIO_ReadPin(SDMMC1_CD_GPIO_Port, SDMMC1_CD_Pin) == GPIO_PIN_RESET);
}

/* Initialise the SD card in 4-bit mode. Returns 1 on success, 0 on failure.
   Non-fatal: never calls Error_Handler() so a bad card can't hang the node. */
static uint8_t SD_TryInit(void)
{
  hsd1.Instance = SDMMC1;
  hsd1.Init.ClockEdge = SDMMC_CLOCK_EDGE_RISING;
  hsd1.Init.ClockBypass = SDMMC_CLOCK_BYPASS_DISABLE;
  hsd1.Init.ClockPowerSave = SDMMC_CLOCK_POWER_SAVE_DISABLE;
  hsd1.Init.BusWide = SDMMC_BUS_WIDE_4B;
  hsd1.Init.HardwareFlowControl = SDMMC_HARDWARE_FLOW_CONTROL_DISABLE;
  hsd1.Init.ClockDiv = 0;
  if (HAL_SD_Init(&hsd1) != HAL_OK)
  {
    return 0;
  }
  if (HAL_SD_ConfigWideBusOperation(&hsd1, SDMMC_BUS_WIDE_4B) != HAL_OK)
  {
    return 0;
  }
  return 1;
}

/* --- RTC time get/set over the host serial link ----------------------- */
/* The RTC runs from the LSE and is backed by VBAT, so it keeps time across
   resets (and across power loss while a coin cell is fitted). We stamp a
   magic value into backup register DR0 the first time the host sets the
   clock so the dashboard can tell "real time" from "unset since cold boot". */
#define RTC_SET_MAGIC 0x53C1u   /* "Set Clock 1" marker in RTC_BKP_DR0 */

/* Emit the current RTC date/time as a single parseable line:
     RTC set=1 2026-06-19 12:34:56
   set=1 means the host has set the clock at least once (DR0 magic present). */
static void RTC_EmitTime(void)
{
  RTC_TimeTypeDef t = {0};
  RTC_DateTypeDef d = {0};
  /* GetTime must be read before GetDate: reading time locks the shadow
     registers and reading date unlocks them again. */
  HAL_RTC_GetTime(&hrtc, &t, RTC_FORMAT_BIN);
  HAL_RTC_GetDate(&hrtc, &d, RTC_FORMAT_BIN);
  uint8_t valid = (HAL_RTCEx_BKUPRead(&hrtc, RTC_BKP_DR0) == RTC_SET_MAGIC);

  char m[48];
  int n = snprintf(m, sizeof(m), "RTC set=%d %04d-%02d-%02d %02d:%02d:%02d\r\n",
                   valid, 2000 + d.Year, d.Month, d.Date,
                   t.Hours, t.Minutes, t.Seconds);
  HAL_UART_Transmit(&huart2, (uint8_t *)m, (uint16_t)n, HAL_MAX_DELAY);
}

/* Parse "YYYY-MM-DD HH:MM:SS" and load it into the RTC. The host sends this
   from "time set ...". Returns 1 on success, 0 on a malformed/out-of-range
   string (the RTC is left unchanged in that case). */
static uint8_t RTC_SetFromString(const char *s)
{
  int yr, mo, da, hh, mm, ss;
  if (sscanf(s, "%d-%d-%d %d:%d:%d", &yr, &mo, &da, &hh, &mm, &ss) != 6)
    return 0;
  if (yr < 2000 || yr > 2099 || mo < 1 || mo > 12 || da < 1 || da > 31 ||
      hh > 23 || mm > 59 || ss > 59)
    return 0;

  RTC_DateTypeDef d = {0};
  RTC_TimeTypeDef t = {0};
  d.Year    = (uint8_t)(yr - 2000);
  d.Month   = (uint8_t)mo;
  d.Date    = (uint8_t)da;
  d.WeekDay = RTC_WEEKDAY_MONDAY;   /* host doesn't track weekday; placeholder */
  t.Hours          = (uint8_t)hh;
  t.Minutes        = (uint8_t)mm;
  t.Seconds        = (uint8_t)ss;
  t.DayLightSaving = RTC_DAYLIGHTSAVING_NONE;
  t.StoreOperation = RTC_STOREOPERATION_RESET;
  if (HAL_RTC_SetTime(&hrtc, &t, RTC_FORMAT_BIN) != HAL_OK) return 0;
  if (HAL_RTC_SetDate(&hrtc, &d, RTC_FORMAT_BIN) != HAL_OK) return 0;
  HAL_RTCEx_BKUPWrite(&hrtc, RTC_BKP_DR0, RTC_SET_MAGIC);
  return 1;
}

/* --- RTC backup-cell (VBAT) voltage via the internal ADC channel ---------- */
/* The STM32L4 routes VBAT through an on-chip /3 bridge to an internal ADC
   channel, so we can read the coin cell with no extra parts. ADC1 is otherwise
   set up as an (idle) 4-channel scan for the planned analog sensors; we borrow
   rank 1 for a single VBAT conversion and put channel 5 back when done.
   VDDA is assumed = 3.300 V (regulated rail); good to a few % — plenty to tell
   a healthy CR2032 (~3.0 V) from a weak (<2.4 V) or missing (~0 V) cell.
   NOTE: only meaningful when the board's "VBAT Power Jumper" feeds the coin
   cell (BT1); if VBAT is strapped to 3V3 this just reports ~3.3 V. */
static uint8_t RTC_ReadVbat_mV(uint32_t *vbat_mv)
{
  ADC_ChannelConfTypeDef sConfig = {0};
  uint8_t ok = 0;

  sConfig.Channel      = ADC_CHANNEL_VBAT;
  sConfig.Rank         = ADC_REGULAR_RANK_1;
  sConfig.SamplingTime = ADC_SAMPLETIME_640CYCLES_5;   /* bridge needs long Ts */
  sConfig.SingleDiff   = ADC_SINGLE_ENDED;
  sConfig.OffsetNumber = ADC_OFFSET_NONE;
  sConfig.Offset       = 0;
  if (HAL_ADC_ConfigChannel(&hadc1, &sConfig) == HAL_OK &&
      HAL_ADC_Start(&hadc1) == HAL_OK)
  {
    if (HAL_ADC_PollForConversion(&hadc1, 10) == HAL_OK)
    {
      uint32_t raw = HAL_ADC_GetValue(&hadc1);       /* 12-bit, VBAT/3 at pin */
      uint32_t at_pin_mv = (raw * 3300U) / 4095U;
      *vbat_mv = at_pin_mv * 3U;                     /* undo the /3 bridge */
      ok = 1;
    }
    HAL_ADC_Stop(&hadc1);
  }

  /* restore rank 1 to its original external channel (PA0 / ADC_CHANNEL_5) */
  sConfig.Channel = ADC_CHANNEL_5;
  HAL_ADC_ConfigChannel(&hadc1, &sConfig);
  return ok;
}

/* --- status OLED rendering -------------------------------------------------- */
/* A small multi-screen UI for the 128x64 SSD1306. The main loop cycles
   OLED_RenderScreen(0..OLED_SCREEN_COUNT-1) every 5 s. Each screen draws an
   inverted title bar (with a "n/N" page indicator) plus a few value rows, all
   read fresh from the sensors at draw time. Formatting is integer-only to match
   the nano-printf build (no %f). All draws no-op if the panel is absent. */
#define OLED_SCREEN_COUNT 5
#define OLED_HDR_H        11           /* title-bar height in pixels           */

/* Draw a string horizontally centred on the panel at row y. */
static void OLED_Center(int y, const char *s, uint8_t scale, SSD1306_Color color)
{
  int x = (SSD1306_WIDTH - SSD1306_TextWidth(s, scale)) / 2;
  SSD1306_WriteStringAt(&oled, x, y, s, scale, color);
}

/* Draw a little sun: a filled disc of radius r at (cx,cy) with eight short rays
   (4 cardinal + 4 diagonal) standing off the rim. Used on the boot splash. */
static void OLED_DrawSun(int cx, int cy, int r)
{
  for (int dy = -r; dy <= r; dy++)
    for (int dx = -r; dx <= r; dx++)
      if (dx * dx + dy * dy <= r * r)
        SSD1306_DrawPixel(&oled, cx + dx, cy + dy, SSD1306_WHITE);

  static const int8_t dir[8][2] = {
    { 0,-1}, { 0, 1}, {-1, 0}, { 1, 0},   /* N S W E         */
    {-1,-1}, { 1,-1}, {-1, 1}, { 1, 1}    /* NW NE SW SE     */
  };
  for (int i = 0; i < 8; i++)
    for (int d = r + 2; d <= r + 4; d++)   /* 3-px ray, offset off the rim */
      SSD1306_DrawPixel(&oled, cx + dir[i][0] * d, cy + dir[i][1] * d, SSD1306_WHITE);
}

/* Render the boot splash: rounded border, sun motif, bold title and a tagline.
   No-ops if the panel isn't present (all primitives guard on oled.present). */
static void OLED_Splash(void)
{
  if (!oled.present)
    return;
  SSD1306_Clear(&oled);

  /* Rounded outer frame (draw the rectangle, then knock out the 4 corners). */
  SSD1306_DrawRect(&oled, 0, 0, SSD1306_WIDTH, SSD1306_HEIGHT, SSD1306_WHITE);
  SSD1306_DrawPixel(&oled, 0, 0, SSD1306_BLACK);
  SSD1306_DrawPixel(&oled, SSD1306_WIDTH - 1, 0, SSD1306_BLACK);
  SSD1306_DrawPixel(&oled, 0, SSD1306_HEIGHT - 1, SSD1306_BLACK);
  SSD1306_DrawPixel(&oled, SSD1306_WIDTH - 1, SSD1306_HEIGHT - 1, SSD1306_BLACK);

  OLED_DrawSun(64, 11, 4);                       /* sun centred near the top   */
  OLED_Center(24, "SolarSense", 2, SSD1306_WHITE); /* bold title (12x16 cells) */
  SSD1306_DrawHLine(&oled, 39, 44, 50, SSD1306_WHITE); /* divider under title  */
  OLED_Center(50, "weather node  v1", 1, SSD1306_WHITE);

  SSD1306_Display(&oled);
}

/* Format a centi-unit fixed-point value (e.g. 2345 -> "23.45 C"), sign-aware. */
static void OLED_FmtCenti(char *o, size_t n, int32_t v, const char *unit)
{
  int neg = (v < 0);
  uint32_t a = (uint32_t)(neg ? -v : v);
  snprintf(o, n, "%s%lu.%02lu%s", neg ? "-" : "",
           (unsigned long)(a / 100U), (unsigned long)(a % 100U), unit);
}

/* Format a tenths fixed-point value (e.g. 872 -> "87.2 %"), sign-aware. */
static void OLED_FmtTenths(char *o, size_t n, int32_t v, const char *unit)
{
  int neg = (v < 0);
  uint32_t a = (uint32_t)(neg ? -v : v);
  snprintf(o, n, "%s%lu.%lu%s", neg ? "-" : "",
           (unsigned long)(a / 10U), (unsigned long)(a % 10U), unit);
}

/* Draw the inverted title bar with a right-aligned "screen+1/N" page chip. */
static void OLED_Header(const char *title, uint8_t screen)
{
  SSD1306_FillRect(&oled, 0, 0, SSD1306_WIDTH, OLED_HDR_H, SSD1306_WHITE);
  SSD1306_WriteStringAt(&oled, 2, 2, title, 1, SSD1306_BLACK);

  char page[8];
  snprintf(page, sizeof(page), "%u/%u", (unsigned)(screen + 1), OLED_SCREEN_COUNT);
  SSD1306_WriteStringAt(&oled, SSD1306_WIDTH - SSD1306_TextWidth(page, 1) - 2, 2,
                        page, 1, SSD1306_BLACK);
}

/* Right-aligned value at row y (keeps the label left, value flush-right). */
static void OLED_Row(int y, const char *label, const char *value)
{
  SSD1306_WriteStringAt(&oled, 2, y, label, 1, SSD1306_WHITE);
  SSD1306_WriteStringAt(&oled, SSD1306_WIDTH - SSD1306_TextWidth(value, 1) - 2, y,
                        value, 1, SSD1306_WHITE);
}
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
int main(void)
{

  /* MCU Configuration--------------------------------------------------------*/

  /* Reset of all peripherals, Initializes the Flash interface and the Systick. */
  HAL_Init();

  /* Configure the system clock */
  SystemClock_Config();

  /* Configure the peripherals common clocks */
  PeriphCommonClock_Config();

  /* Initialize all configured peripherals */
  MX_GPIO_Init();
  MX_CAN1_Init();
  MX_I2C1_Init();
  /* MX_SDMMC1_SD_Init();  -- replaced by non-fatal init in USER CODE BEGIN 2
     (the generated version calls Error_Handler() if no card is present, which
     would hang the whole node). Re-comment this if you regenerate from CubeMX. */
  MX_SPI1_Init();
  MX_USART2_UART_Init();
  MX_ADC1_Init();
  MX_RTC_Init();
  /* USER CODE BEGIN 2 */
  /* STM32L4 ADC requires calibration before first use; must be done while the
     ADC is enabled but not converting (i.e. right after MX_ADC1_Init). */
  HAL_ADCEx_Calibration_Start(&hadc1, ADC_SINGLE_ENDED);

  uint32_t last_flash = 0;      /* LED_STATUS flash timer (250 ms pulse every 10 s) */
  uint8_t  led_on = 0;          /* current LED_STATUS pulse state */
  uint32_t last_heartbeat = 0;  /* serial heartbeat timer (every 5 s) */
  uint32_t last_alert_chk = 0;  /* battery-alert re-arm check timer (every 5 s) */
  uint32_t heartbeat_count = 0;
  uint32_t last_oled = 0;       /* OLED screen-cycle timer (advance every 5 s) */
  uint8_t  oled_screen = 0;     /* index of the screen currently shown         */

  const char *banner = "\r\nSolarSense v1 boot OK\r\n";
  HAL_UART_Transmit(&huart2, (uint8_t *)banner, strlen(banner), HAL_MAX_DELAY);

  {
    HAL_StatusTypeDef st = CAN_TLM_Start(&hcan1);
    const char *m = (st == HAL_OK) ? "CAN TLM started @500kbps\r\n"
                                   : "CAN TLM start FAILED - CAN TX disabled\r\n";
    HAL_UART_Transmit(&huart2, (uint8_t *)m, strlen(m), HAL_MAX_DELAY);
  }

  /* Card-detect-gated SD init. Only touch the SDMMC when a card is physically
     present; track card-present state so we can react to hot insert/remove. */
  uint8_t sd_ready = 0;                       /* 1 = SD initialised and usable  */
  uint8_t card_present = SD_CardPresent();    /* debounced state of PC6          */

  if (card_present)
  {
    sd_ready = SD_TryInit();
    const char *m = sd_ready ? "SD init OK\r\n"
                             : "SD present but init FAILED - continuing\r\n";
    HAL_UART_Transmit(&huart2, (uint8_t *)m, strlen(m), HAL_MAX_DELAY);
  }
  else
  {
    const char *m = "No SD card detected - continuing\r\n";
    HAL_UART_Transmit(&huart2, (uint8_t *)m, strlen(m), HAL_MAX_DELAY);
  }
  /* LED_ERR reflects "card present but unusable" */
  HAL_GPIO_WritePin(LED_ERR_GPIO_Port, LED_ERR_Pin,
                    (card_present && !sd_ready) ? GPIO_PIN_SET : GPIO_PIN_RESET);

  /* --- MAX17048 fuel gauge + BAT_ALRT (PB13) interrupt ------------------- */
  /* Reconfigure PB13 from plain input to a falling-edge EXTI. ALRT is
     open-drain/active-low, so enable a pull-up and trigger on the falling
     edge. (Done in code so it survives a CubeMX regenerate; if you instead
     set PB13 = GPIO_EXTI13 in CubeMX, remove this block and the handler in
     stm32l4xx_it.c to avoid a duplicate IRQ handler.) */
  {
    GPIO_InitTypeDef alrt = {0};
    alrt.Pin = BAT_ALRT_Pin;
    alrt.Mode = GPIO_MODE_IT_FALLING;
    alrt.Pull = GPIO_PULLUP;
    HAL_GPIO_Init(BAT_ALRT_GPIO_Port, &alrt);
    HAL_NVIC_SetPriority(EXTI15_10_IRQn, 5, 0);
    HAL_NVIC_EnableIRQ(EXTI15_10_IRQn);
  }

  if (MAX17048_Init(&hi2c1) == HAL_OK)
  {
    MAX17048_SetEmptyAlertThreshold(15);        /* alert at <= 15% SOC      */
    MAX17048_SetVoltageAlerts(3.0f, 4.25f);     /* under/over-voltage limits */
    MAX17048_EnableSOCChangeAlert(0);           /* keep SOC-change alert off */
    MAX17048_ClearAlert();

    uint16_t ver = 0; float v = 0.0f, soc = 0.0f;
    MAX17048_ReadVersion(&ver);
    MAX17048_ReadVoltage(&v);
    MAX17048_ReadSOC(&soc);
    /* integer formatting: nano printf has no %f unless -u _printf_float */
    int mv = (int)(v * 1000.0f + 0.5f);
    int soc10 = (int)(soc * 10.0f + 0.5f);
    char m[72];
    int n = snprintf(m, sizeof(m), "MAX17048 ok ver=0x%04X %dmV %d.%d%%\r\n",
                     ver, mv, soc10 / 10, soc10 % 10);
    HAL_UART_Transmit(&huart2, (uint8_t *)m, (uint16_t)n, HAL_MAX_DELAY);
  }
  else
  {
    const char *m = "MAX17048 not found\r\n";
    HAL_UART_Transmit(&huart2, (uint8_t *)m, strlen(m), HAL_MAX_DELAY);
  }

  /* --- INA219 panel current/voltage monitors (I2C1) --------------------- */
  /* Three populated parts (0x40/0x41/0x44); each init is non-fatal so a
     missing/unpopulated panel monitor does not block the node. */
  for (int i = 0; i < INA219_PANEL_COUNT; i++)
  {
    HAL_StatusTypeDef st = INA219_Init(&panel_ina[i], &hi2c1, panel_ina_addr[i]);
    char m[56];
    int n = snprintf(m, sizeof(m), "INA219 P%d @0x%02X %s\r\n",
                     i + 1, panel_ina_addr[i],
                     (st == HAL_OK) ? "ok" : "not found");
    HAL_UART_Transmit(&huart2, (uint8_t *)m, (uint16_t)n, HAL_MAX_DELAY);
  }

  /* --- MAX31855 thermocouple (TC3, PB1) --------------------------------- */
  {
    HAL_StatusTypeDef st = MAX31855_Init(&tc3, &hspi1,
                                         TC3_CS_GPIO_Port, TC3_CS_Pin);
    const char *m = (st == HAL_OK) ? "MAX31855 TC3 ok\r\n"
                                   : "MAX31855 TC3 SPI FAIL\r\n";
    HAL_UART_Transmit(&huart2, (uint8_t *)m, strlen(m), HAL_MAX_DELAY);
  }

  /* --- BMP280 pressure + board temperature (I2C1 @0x76) ----------------- */
  /* Non-fatal: a missing barometer just drops the bmp_* TLM keys. */
  {
    HAL_StatusTypeDef st = BMP280_Init(&bmp, &hi2c1, BMP280_ADDR);
    char m[56];
    int n;
    if (st == HAL_OK)
      n = snprintf(m, sizeof(m), "BMP280 ok @0x%02X id=0x%02X (%s)\r\n",
                   bmp.addr7, bmp.chip_id,
                   (bmp.chip_id == BME280_CHIP_ID) ? "BME280" : "BMP280");
    else
      n = snprintf(m, sizeof(m), "BMP280 not found (last id=0x%02X)\r\n",
                   bmp.chip_id);
    HAL_UART_Transmit(&huart2, (uint8_t *)m, (uint16_t)n, HAL_MAX_DELAY);
  }

  /* --- HX94C humidity/temp probe (4-20 mA loops on ADC1) ---------------- */
  /* Analog-only: nothing to probe, so just record the channels. The loops are
     fed by the +12 V rail, so a meaningful read needs "12v on" first. */
  HX94C_Init(&hx, &hadc1, ADC_CHANNEL_6, ADC_CHANNEL_13, ADC_CHANNEL_5);
  {
    const char *m = "HX94C on ADC RH=IN6 T=IN13 (needs +12 V rail)\r\n";
    HAL_UART_Transmit(&huart2, (uint8_t *)m, strlen(m), HAL_MAX_DELAY);
  }

  /* --- I2C1 bus scan (debug aid) ---------------------------------------- */
  /* Walk the 7-bit address space and report every device that ACKs. Useful to
     confirm the OLED is wired/pulled-up and at what address it actually sits. */
  {
    char m[40];
    int n = snprintf(m, sizeof(m), "I2C1 scan:");
    HAL_UART_Transmit(&huart2, (uint8_t *)m, (uint16_t)n, HAL_MAX_DELAY);
    int found = 0;
    for (uint8_t a = 0x08; a <= 0x77; a++)
    {
      if (HAL_I2C_IsDeviceReady(&hi2c1, (uint16_t)(a << 1), 2, 5) == HAL_OK)
      {
        n = snprintf(m, sizeof(m), " 0x%02X", a);
        HAL_UART_Transmit(&huart2, (uint8_t *)m, (uint16_t)n, HAL_MAX_DELAY);
        found++;
      }
    }
    n = snprintf(m, sizeof(m), found ? "\r\n" : " (none)\r\n");
    HAL_UART_Transmit(&huart2, (uint8_t *)m, (uint16_t)n, HAL_MAX_DELAY);
  }

  /* --- SSD1306 status OLED (I2C1 @0x3C) --------------------------------- */
  /* Fully optional: the panel is probed at boot and, if it doesn't ACK,
     oled.present stays 0 and the firmware runs exactly as before -- the screen
     cycle is skipped and every draw call is an internal no-op. When present,
     show an elegant splash before the screens start cycling. */
  {
    HAL_StatusTypeDef st = SSD1306_Init(&oled, &hi2c1, SSD1306_ADDR);
    if (oled.present)
      OLED_Splash();
    const char *m = (st == HAL_OK) ? "SSD1306 OLED ok @0x3C\r\n"
                                   : "SSD1306 OLED not found - display disabled\r\n";
    HAL_UART_Transmit(&huart2, (uint8_t *)m, strlen(m), HAL_MAX_DELAY);
  }

  /* --- SEN66 air quality sensor (I2C1 @0x6B) ---------------------------- */
  /* Probed only if the I2C scan found it.  Init issues a soft-reset and
     starts continuous measurement; first valid readings arrive ~1 s later. */
  {
    HAL_StatusTypeDef st = SEN66_Init(&sen, &hi2c1);
    char m[56];
    int n = snprintf(m, sizeof(m), "SEN66 %s @0x6B\r\n",
                     (st == HAL_OK) ? "ok" : "not found");
    HAL_UART_Transmit(&huart2, (uint8_t *)m, (uint16_t)n, HAL_MAX_DELAY);
  }
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

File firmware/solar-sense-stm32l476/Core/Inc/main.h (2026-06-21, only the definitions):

#define ADC_UV_Pin GPIO_PIN_0
#define ADC_UV_GPIO_Port GPIOA
#define ADC_HX94C_RH_Pin GPIO_PIN_1
#define ADC_HX94C_RH_GPIO_Port GPIOA
#define TC1_CS_Pin GPIO_PIN_4
#define TC1_CS_GPIO_Port GPIOA
#define ADC_HX94C_TEMP_Pin GPIO_PIN_4
#define ADC_HX94C_TEMP_GPIO_Port GPIOC
#define RAIN_AO_Pin GPIO_PIN_5
#define RAIN_AO_GPIO_Port GPIOC
#define TC2_CS_Pin GPIO_PIN_0
#define TC2_CS_GPIO_Port GPIOB
#define TC3_CS_Pin GPIO_PIN_1
#define TC3_CS_GPIO_Port GPIOB
#define EN_12V_Pin GPIO_PIN_2
#define EN_12V_GPIO_Port GPIOB
#define LORA_RESET_Pin GPIO_PIN_10
#define LORA_RESET_GPIO_Port GPIOB
#define LORA_DIO1_Pin GPIO_PIN_11
#define LORA_DIO1_GPIO_Port GPIOB
#define LORA_BUSY_Pin GPIO_PIN_12
#define LORA_BUSY_GPIO_Port GPIOB
#define BAT_ALRT_Pin GPIO_PIN_13
#define BAT_ALRT_GPIO_Port GPIOB
#define CN3791_CHRG_Pin GPIO_PIN_14
#define CN3791_CHRG_GPIO_Port GPIOB
#define CN3791_DONE_Pin GPIO_PIN_15
#define CN3791_DONE_GPIO_Port GPIOB
#define SDMMC1_CD_Pin GPIO_PIN_6
#define SDMMC1_CD_GPIO_Port GPIOC
#define LORA_CS_Pin GPIO_PIN_8
#define LORA_CS_GPIO_Port GPIOA
#define LED_STATUS_Pin GPIO_PIN_3
#define LED_STATUS_GPIO_Port GPIOB
#define LED_ERR_Pin GPIO_PIN_4
#define LED_ERR_GPIO_Port GPIOB
#define RAIN_DET_Pin GPIO_PIN_5
#define RAIN_DET_GPIO_Port GPIOB

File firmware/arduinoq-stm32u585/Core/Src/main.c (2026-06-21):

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
/* Includes ------------------------------------------------------------------*/
#include "main.h"

/* USER CODE BEGIN Includes */
#include <stdio.h>
#include "can_protocol.h"
#include "can_unpack.h"
/* USER CODE END Includes */


FDCAN_HandleTypeDef hfdcan1;

UART_HandleTypeDef hlpuart1;

void SystemClock_Config(void);
static void MX_GPIO_Init(void);
static void MX_FDCAN1_Init(void);
static void MX_LPUART1_UART_Init(void);
static void MX_ICACHE_Init(void);
/**
  * @brief  The application entry point.
  * @retval int
  */
int main(void)
{
  HAL_Init();
  SystemClock_Config();
  MX_GPIO_Init();
  MX_FDCAN1_Init();
  MX_LPUART1_UART_Init();
  MX_ICACHE_Init();

  /* USER CODE BEGIN 2 */
  setvbuf(stdout, NULL, _IONBF, 0);
  printf("SolarSense CAN receiver — QSTM U585\r\n");

  FDCAN_FilterTypeDef sFilterConfig;
  sFilterConfig.IdType       = FDCAN_STANDARD_ID;
  sFilterConfig.FilterIndex  = 0;
  sFilterConfig.FilterType   = FDCAN_FILTER_MASK;
  sFilterConfig.FilterConfig = FDCAN_FILTER_TO_RXFIFO0;
  sFilterConfig.FilterID1    = 0x000;  /* accept all standard IDs */
  sFilterConfig.FilterID2    = 0x000;
  HAL_FDCAN_ConfigFilter(&hfdcan1, &sFilterConfig);
  HAL_FDCAN_ConfigGlobalFilter(&hfdcan1,
      FDCAN_REJECT, FDCAN_REJECT,
      FDCAN_FILTER_REMOTE, FDCAN_FILTER_REMOTE);
  HAL_FDCAN_Start(&hfdcan1);
  printf("CAN init OK — listening at 500kbps\r\n");
  /* USER CODE END 2 */

  while (1)
  {
    /* USER CODE BEGIN WHILE */
    /* PH10 (red): 1 Hz heartbeat blink, independent of CAN traffic */
    static uint32_t last_blink = 0;
    static uint32_t last_rx    = 0;
    uint32_t now = HAL_GetTick();
    if (now - last_blink >= 500) {
      HAL_GPIO_TogglePin(GPIOH, GPIO_PIN_10);
      last_blink = now;
    }
    /* PH14 (green): solid ON while frames are arriving, OFF when the bus goes quiet */
    HAL_GPIO_WritePin(GPIOH, GPIO_PIN_14,
                      (last_rx != 0 && now - last_rx < 200) ? GPIO_PIN_SET : GPIO_PIN_RESET);

    if (HAL_FDCAN_GetRxFifoFillLevel(&hfdcan1, FDCAN_RX_FIFO0) > 0) {
      FDCAN_RxHeaderTypeDef rxHeader;
      uint8_t rxData[8];
      HAL_FDCAN_GetRxMessage(&hfdcan1, FDCAN_RX_FIFO0, &rxHeader, rxData);
      last_rx = now;  /* PH14 (green): mark RX activity (drives the LED above) */

      uint32_t id   = rxHeader.Identifier;
      uint32_t tick = HAL_GetTick();

      switch (id) {
      case SS_ID_PANEL1: {
        SS_Panel_t p; can_unpack_panel(rxData, &p);
        printf("[%06lu] RX 0x101 P1_REF  V=%umV  I=%ldµA  P=%ldµW\r\n",
               (unsigned long)tick, (unsigned)p.v_mv, (long)p.i_ua, (long)p.p_uw);
        break;
      }
      case SS_ID_PANEL2: {
        SS_Panel_t p; can_unpack_panel(rxData, &p);
        printf("[%06lu] RX 0x102 P2_SOIL V=%umV  I=%ldµA  P=%ldµW\r\n",
               (unsigned long)tick, (unsigned)p.v_mv, (long)p.i_ua, (long)p.p_uw);
        break;
      }
      case SS_ID_PANEL3: {
        SS_Panel_t p; can_unpack_panel(rxData, &p);
        printf("[%06lu] RX 0x103 P3_SOIL V=%umV  I=%ldµA  P=%ldµW\r\n",
               (unsigned long)tick, (unsigned)p.v_mv, (long)p.i_ua, (long)p.p_uw);
        break;
      }
      case SS_ID_UV: {
        SS_UV_t u; can_unpack_uv(rxData, &u);
        printf("[%06lu] RX 0x104 UV      counts=%u\r\n",
               (unsigned long)tick, (unsigned)u.uv_counts);
        break;
      }
      case SS_ID_THERMO: {
        SS_Thermo_t t; can_unpack_thermo(rxData, &t);
        printf("[%06lu] RX 0x201 TC      surface=%.1fC  cold=%.1fC\r\n",
               (unsigned long)tick,
               t.surface_c10 / 10.0f, t.cold_c10 / 10.0f);
        break;
      }
      case SS_ID_BATTERY: {
        SS_Battery_t b; can_unpack_battery(rxData, &b);
        printf("[%06lu] RX 0x202 BAT     %umV  %u%%\r\n",
               (unsigned long)tick, (unsigned)b.bat_mv, (unsigned)b.soc);
        break;
      }
      case SS_ID_SEN66_PM: {
        SS_SEN66_PM_t pm; can_unpack_sen66_pm(rxData, &pm);
        printf("[%06lu] RX 0x301 PM      1.0=%.1f  2.5=%.1f  4=%.1f  10=%.1f ug/m3\r\n",
               (unsigned long)tick,
               pm.pm1_x10 / 10.0f, pm.pm25_x10 / 10.0f,
               pm.pm4_x10 / 10.0f, pm.pm10_x10 / 10.0f);
        break;
      }
      case SS_ID_SEN66_GAS: {
        SS_SEN66_Gas_t g; can_unpack_sen66_gas(rxData, &g);
        printf("[%06lu] RX 0x302 GAS     CO2=%uppm  VOC=%u  NOx=%u\r\n",
               (unsigned long)tick,
               (unsigned)g.co2_ppm, (unsigned)g.voc, (unsigned)g.nox);
        break;
      }
      case SS_ID_BME280: {
        SS_BME280_t b; can_unpack_bme280(rxData, &b);
        printf("[%06lu] RX 0x303 BME     P=%luPa  T=%.2fC\r\n",
               (unsigned long)tick,
               (unsigned long)b.press_pa, b.temp_c100 / 100.0f);
        break;
      }
      case SS_ID_HX94C_RAIN: {
        SS_HX94C_Rain_t h; can_unpack_hx94c_rain(rxData, &h);
        printf("[%06lu] RX 0x304 ENV     RH=%.2f%%  T=%.2fC  rain=%s\r\n",
               (unsigned long)tick,
               h.rh_pct100 / 100.0f, h.temp_c100 / 100.0f,
               h.rain ? "WET" : "DRY");
        break;
      }
      case SS_ID_HEARTBEAT: {
        SS_Heartbeat_t hb; can_unpack_heartbeat(rxData, &hb);
        printf("[%06lu] HB  seq=%lu  flags=0x%02X\r\n",
               (unsigned long)tick, (unsigned long)hb.seq, (unsigned)hb.flags);
        break;
      }
      default:
        printf("[%06lu] RX 0x%03lX  ? [%02X %02X %02X %02X %02X %02X %02X %02X]\r\n",
               (unsigned long)tick, (unsigned long)id,
               rxData[0], rxData[1], rxData[2], rxData[3],
               rxData[4], rxData[5], rxData[6], rxData[7]);
        break;
      }
    }
    /* USER CODE END WHILE */
  }
}

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
/* USER CODE BEGIN 4 */
int __io_putchar(int ch)
{
  HAL_UART_Transmit(&hlpuart1, (uint8_t *)&ch, 1, HAL_MAX_DELAY);
  return ch;
}
/* USER CODE END 4 */
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


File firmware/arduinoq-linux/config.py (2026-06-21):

import os

# ---------------------------------------------------------------------------
# Serial port — ArduinoQ LPUSART → Linux
# ---------------------------------------------------------------------------
SERIAL_PORT = "/dev/ttyHS1"
SERIAL_BAUD = 115200

# ---------------------------------------------------------------------------
# TCP server — LabVIEW connects here (over LAN from Windows PC)
# ---------------------------------------------------------------------------
TCP_HOST = "0.0.0.0"
TCP_PORT = 9000

# ---------------------------------------------------------------------------
# Soiling alert thresholds (power ratio vs reference panel)
# ---------------------------------------------------------------------------
THRESHOLD_SCHEDULE = 0.90   # below 90 % → schedule a clean
THRESHOLD_URGENT   = 0.75   # below 75 % → clean immediately

# Which INA219 panel is the always-clean reference (0=P1, 1=P2, 2=P3)
REFERENCE_PANEL = 2          # P3 = shaded/covered reference

# ---------------------------------------------------------------------------
# UV sensor calibration
# ---------------------------------------------------------------------------
# GUVA-S12S: UV index ≈ uv_mv / UV_MV_PER_INDEX.  Tune after outdoor calibration.
UV_MV_PER_INDEX = 110

# ---------------------------------------------------------------------------
# Edge Impulse
# ---------------------------------------------------------------------------
EI_WINDOW_SECONDS = 30
EI_API_KEY        = os.environ.get("EI_API_KEY", "ei_REPLACE_ME")
EI_INGEST_URL     = "https://ingestion.edgeimpulse.com/api/training/data"
EI_CLASSIFY_URL   = os.environ.get("EI_CLASSIFY_URL", "")   # REST classify endpoint
EI_DEVICE_NAME    = "solarsense-node-01"

# ---------------------------------------------------------------------------
# Legacy MQTT settings (mqtt_bridge.py only — not used by serial_bridge.py)
# ---------------------------------------------------------------------------
MQTT_HOST      = "192.168.1.100"
MQTT_PORT      = 1883
MQTT_KEEPALIVE = 60
MQTT_TOPIC_ROOT = "solarsense/#"

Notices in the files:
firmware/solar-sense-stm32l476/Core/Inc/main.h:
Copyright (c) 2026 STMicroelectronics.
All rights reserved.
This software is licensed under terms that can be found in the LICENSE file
